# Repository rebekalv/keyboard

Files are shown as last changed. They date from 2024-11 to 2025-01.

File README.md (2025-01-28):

# 🚀 Build Your Dream Mechanical LED Keyboard with AVR DU! 🌟

Ever wanted to craft your own custom mechanical keyboard? Here's how I brought mine to life, step-by-step! 🛠️✨

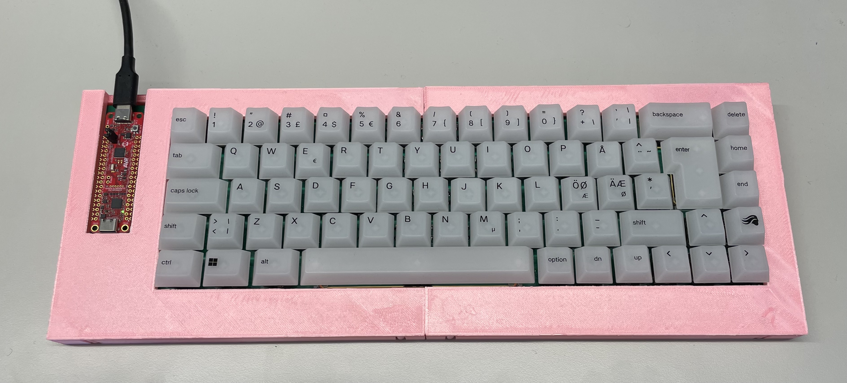
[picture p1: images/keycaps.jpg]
Mechanical Keyboard


---

### 🔧 **Project Highlights:**

- **Microcontroller Magic 🧠:**  
  Powered by the AVR64DU32 on a Curiosity Nano (cnano), this keyboard communicates seamlessly via USB-C using the Human Interface Device (HID) class. No soldering, no hassle—just plug and play!

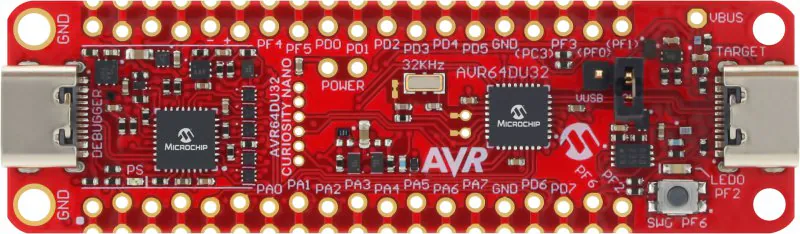
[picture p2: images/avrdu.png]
Microcontroller AVRDU
  

- **Custom PCB in KiCad 💻:**  
  I designed a PCB to eliminate complex wiring, ensuring a sleek, professional layout. KiCad made it easy to customize my PCB, but managing library includes can be somewhat cumbersome.

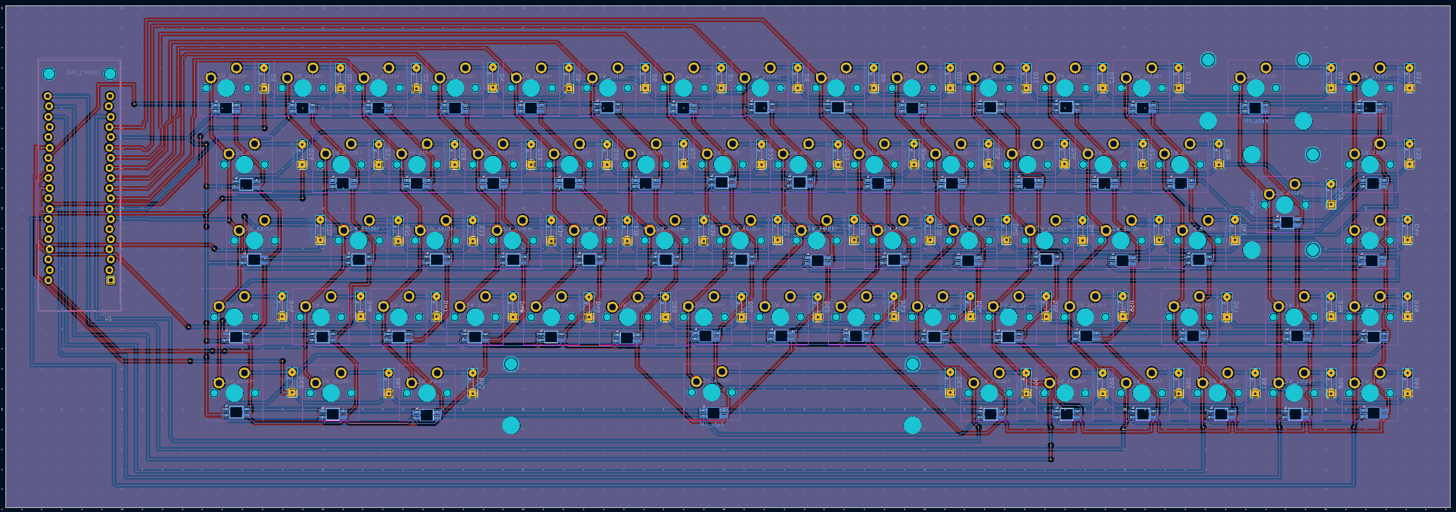
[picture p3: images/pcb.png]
pcb kicad
    

- **Light Up the Keys! 🌈:**  
  Each key features a NeoPixel-compatible LED beneath, adding customizable lighting effects. LEDs are programmed directly alongside the keyboard firmware using MPLAB X IDE. Imagine the rainbow possibilities! 🌟 Due to a pcb schematic error (red circles), the ground and led data pin were swapped. Which is why lighting the leds will have to wait untill the arrival of a new pcb.

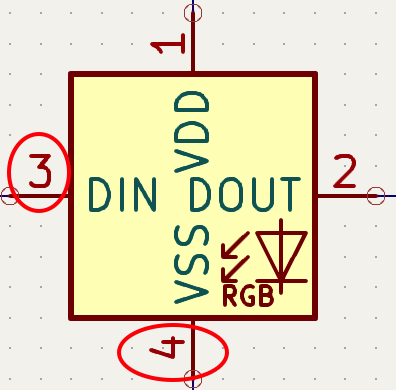
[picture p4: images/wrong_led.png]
wrong leds
     
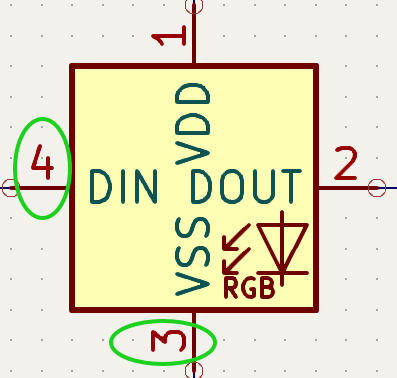
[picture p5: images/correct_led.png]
correct leds
     

- **Custom 3D-Printed Case 🎨:**  
  The case is here! Designed with simplicity and style, it’s split into five parts for easy 3D printing 🖨️. All .stl files are in the 3D_keyboard_case folder, ready to print and assemble.
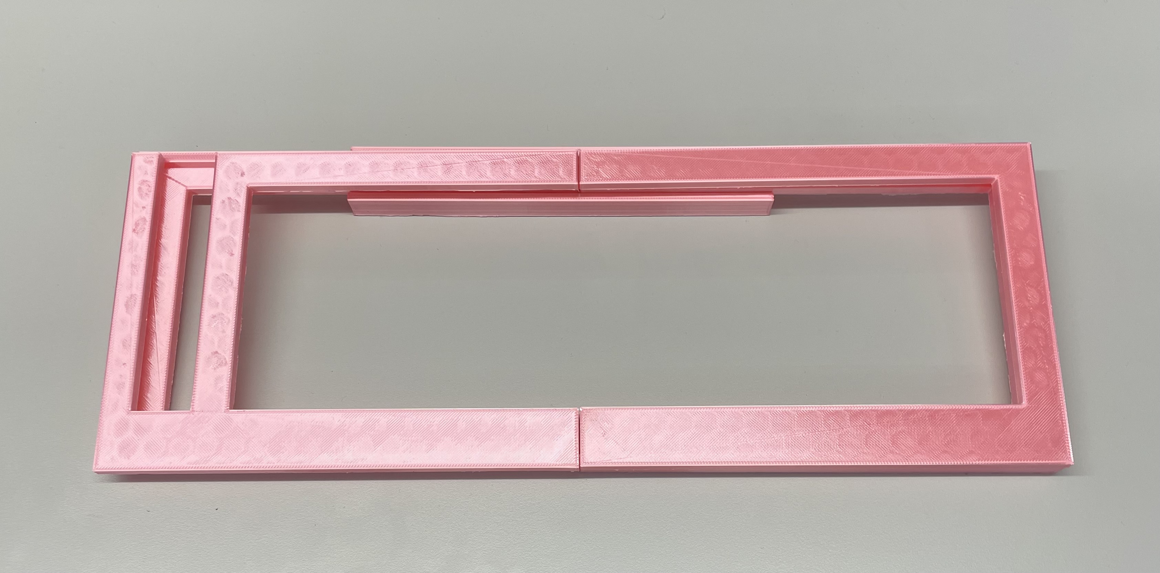
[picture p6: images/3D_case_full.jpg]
3D case
    

---

🎹 **DIY Tip:** If you're diving into mechanical keyboard projects, understanding matrix scanning and pcb tools like KiCad will open up endless customization!

Ready to create your own masterpiece? Let's type into the future! 🚀

## Component List
- Microcontroller: [AVR64DU32 curiosity nano](https://www.microchip.com/en-us/development-tool/ev59f82a)
- LEDs: [3.2x2.8mm sk6812 mini-E, reverse mount neopixel LEDs](https://www.aliexpress.com/item/1005005193716172.html)
- Diodes: [1N4148 DO-35 through hole diodes](https://www.aliexpress.com/item/1005006127068810.html)
- Switches: [JWICK V2 T1 Black Blue Tactile Switch 5pin RGB, Cherry MX](https://www.aliexpress.com/item/1005004226805283.html)
- Stabilizers for big switches: [PCB mounted Cherry MX stabilizers](https://es.aliexpress.com/item/1005004229140548.html)
- See-through Keycaps: [Polychroma V2 RGB Keycaps, Nordic ISO](https://www.maxgaming.no/no/keycaps/polychroma-v2-rgb-keycaps-131-pbt-polykarbonat-caps-nordic-iso)

## Milestones
1. 🖥️ [**Layout Creation:**](#layout-creation) Sketch the perfect keyboard design.
2. 🛠️ [**AVR Pin Setup:**](#avr-pin-setup) Map out pin connections and wiring.
3. 🔌 [**Component Selection:**](#component-selection) Choose the ideal switches, diodes, and LEDs.
4. 📐 [**PCB Design:**](#pcb-design) Craft your circuit board in KiCad and send it for manufacturing.
5. 🔧 [**Assembly:**](#assembly) Solder components onto the PCB.
6. 💻 [**Firmware Development:**](#firmware-development) Program the AVR for matrix scanning.
7. 🌈 **LED Integration:** Synchronize lighting with the firmware. (Suspended untill new pcb)
8. 🏗️ [**Case Design:**](#case-design) Plan and 3D print your custom keyboard case
9. 📚 **Document Everything:** Share your journey and insights.

### Layout Creation
I used https://www.keyboard-layout-editor.com/ to create an initial layout for my keyboard. If you want to regenerate this design, go to the website and insert the raw json data from `keyboard_layout/raw_data.json`. 

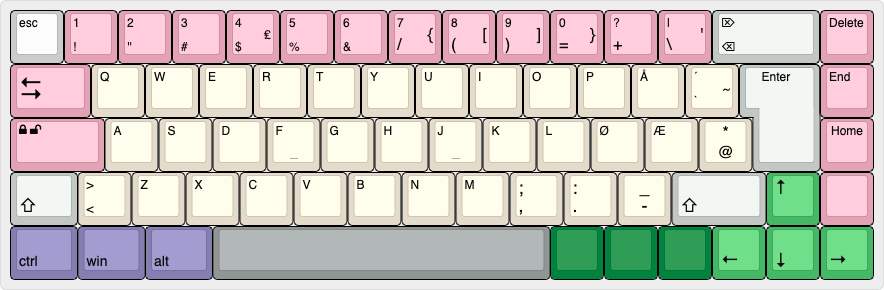
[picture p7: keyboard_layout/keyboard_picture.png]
keyboard layout
 

When your design is ready, you will need the outline of the keyboard for the pcb design. Go to https://plate.keeb.io/ and paste the raw json data. Then you can then download the outline as an svg file.

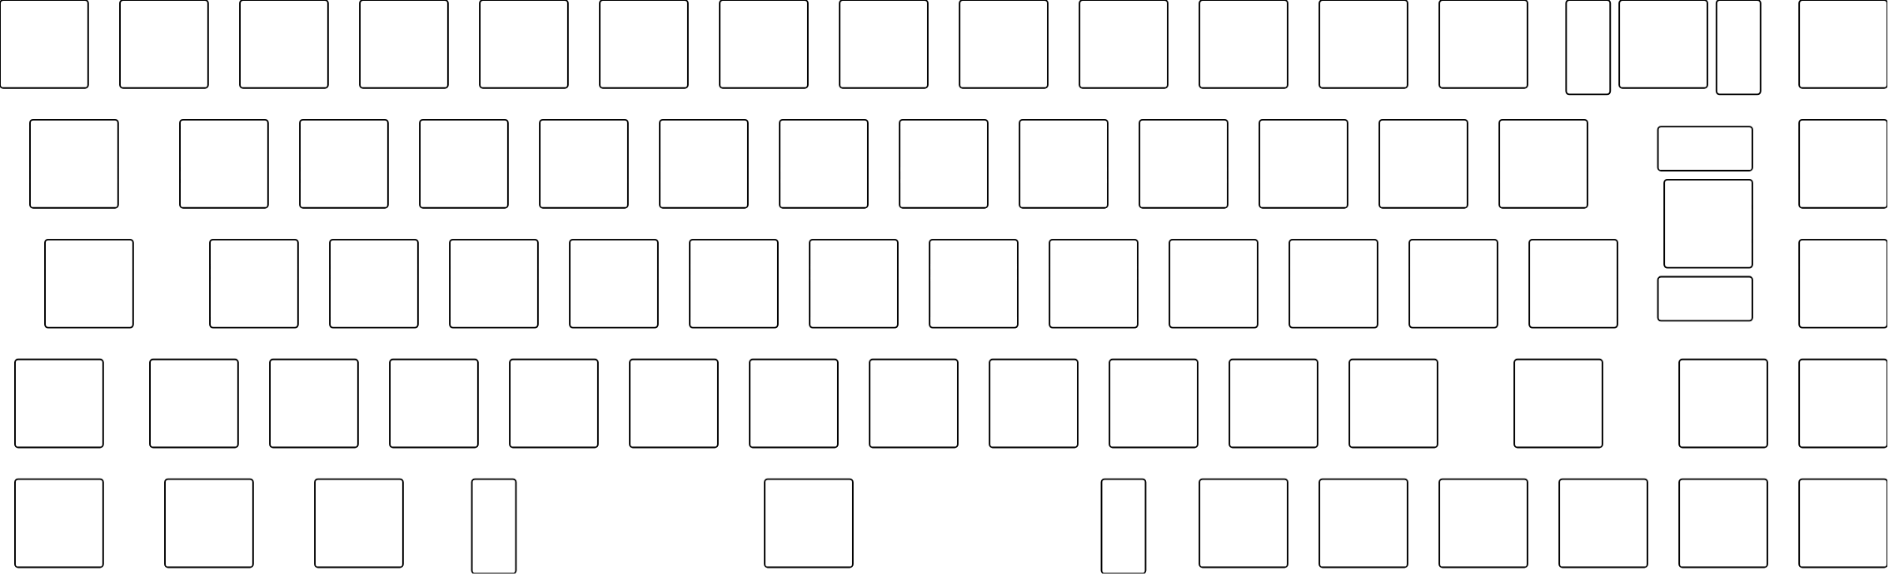
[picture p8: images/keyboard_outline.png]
keyboard outline


### AVR Pin Setup
The important thing in this step is to map out how many pins your keyboard needs, and if your microcontroller can provide that. My keyboard needs 5 rows and 15 columns, hence 20 pins. Looking at pinout on the [cnano website](https://www.microchip.com/en-us/development-tool/ev59f82a), it has 24 port pins. Excluding the usb detect, LED control and debugger LED pin, we are left with 21 available pins, which is enough for our keyboard.

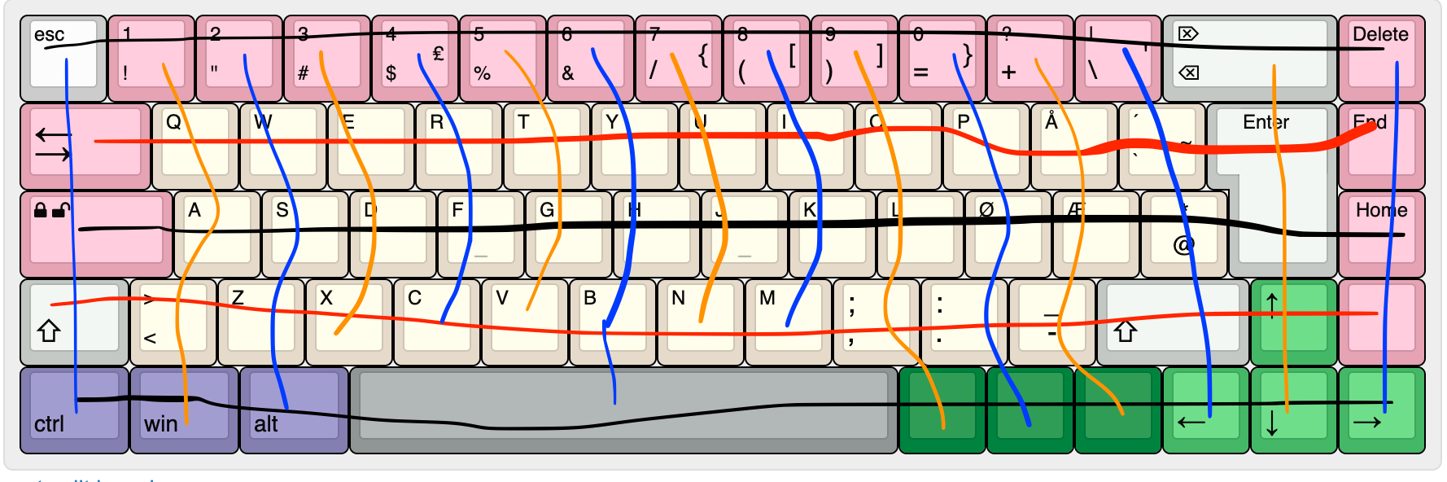
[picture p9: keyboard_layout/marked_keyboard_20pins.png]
keyboard columns and rows


Reading the datasheet for the avrdu, it reveals that the usart0 signal can be routed to 4 possible transmission pins. We will use this signal to control the leds, and I chose alternative 3, PD4, as the LED_DATA pin.

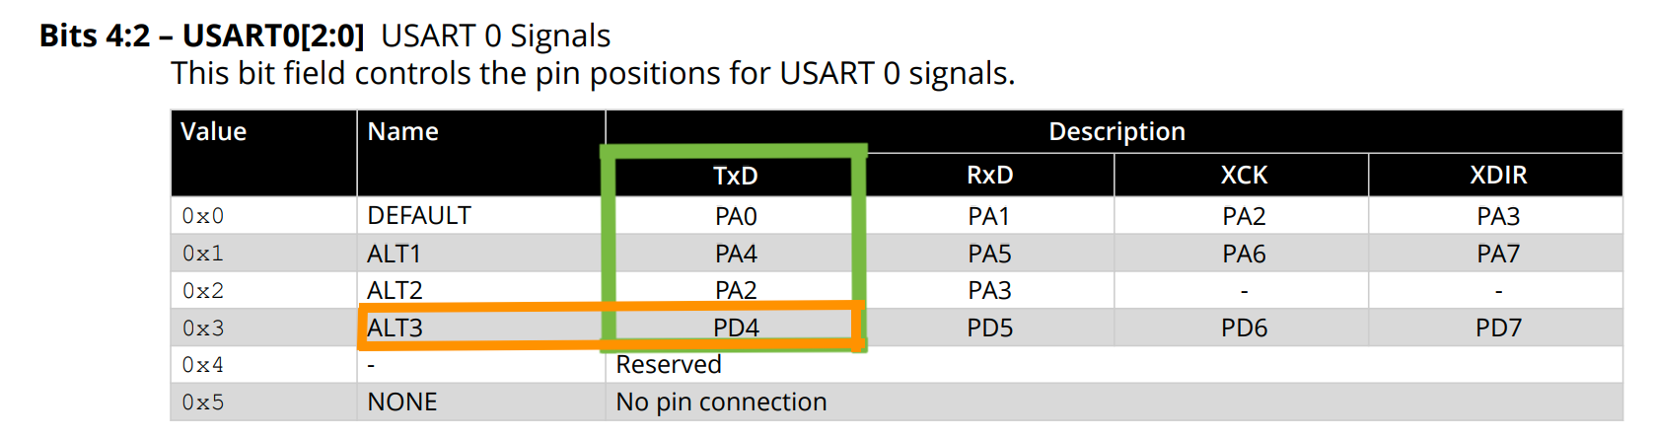
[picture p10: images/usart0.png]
usart0 transmission options


### Component Selection
Check the [component list](#component-list) for handy links! Going with popular, widely-used components simplifies the PCB design, because pre-existing footprints save time and effort. That's why I selected the reliable Cherry MX switches alongside the 1N4148 DO-35 diodes. Some Cherry MX switches feature an opening for LEDs to shine through, perfect for illuminating your keyboard (see the marking on the picture below). I opted to solder everything manually, so I chose through-hole diodes and ensured the LEDs were hand-solderable.

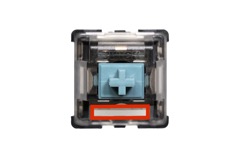
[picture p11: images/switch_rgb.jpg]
switch

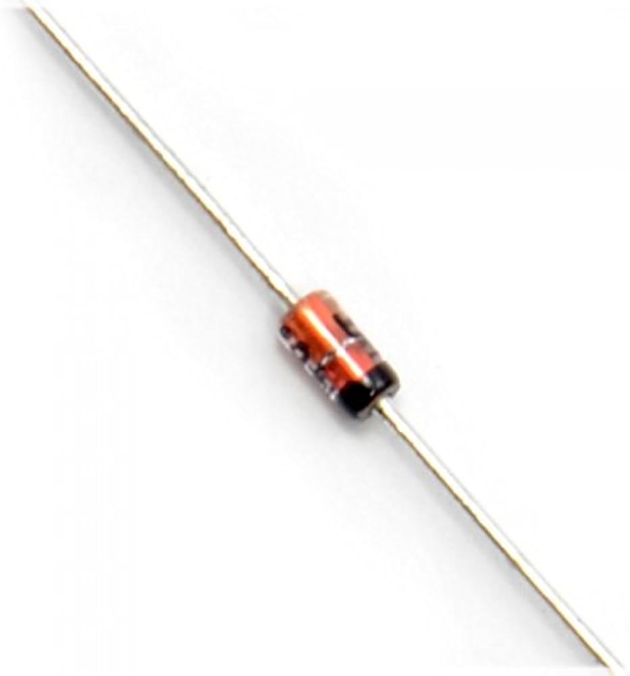
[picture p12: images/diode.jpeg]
diode

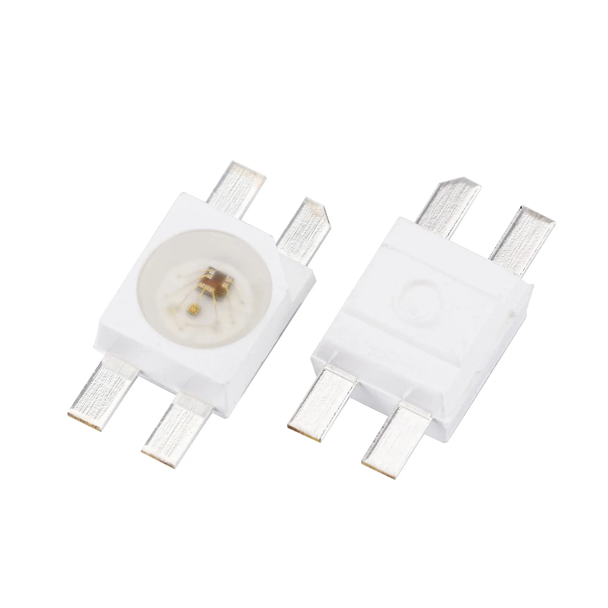
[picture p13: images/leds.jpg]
led


Pro tip: Also, go for PCB-mounted stabilizers—they're far easier to install than plate mounted, and the PCB outline already accommodates them.

stabilizer

### PCB Design
Now the real fun begins! 🚀 Or maybe the challenge? 🛠️

#### Schematic
In KiCad, you’ll start by creating a clear and accurate schematic. This is the blueprint for your circuit, mapping out connections between components and ensuring everything fits together logically. Double-check those connections and that the schema matches the data sheets—it’s much easier to catch errors here than on a finished PCB!

In my schematics, I connected all my switches and diodes and assigned them rows and columns as described in the keyboard outline. Further, I designed a symbol for the avrdu cnano, with the pinout corresponding to the datasheet. I connected the rows and columns to available port pins, and the grounds, voltages and led pin to their corresponding pins.

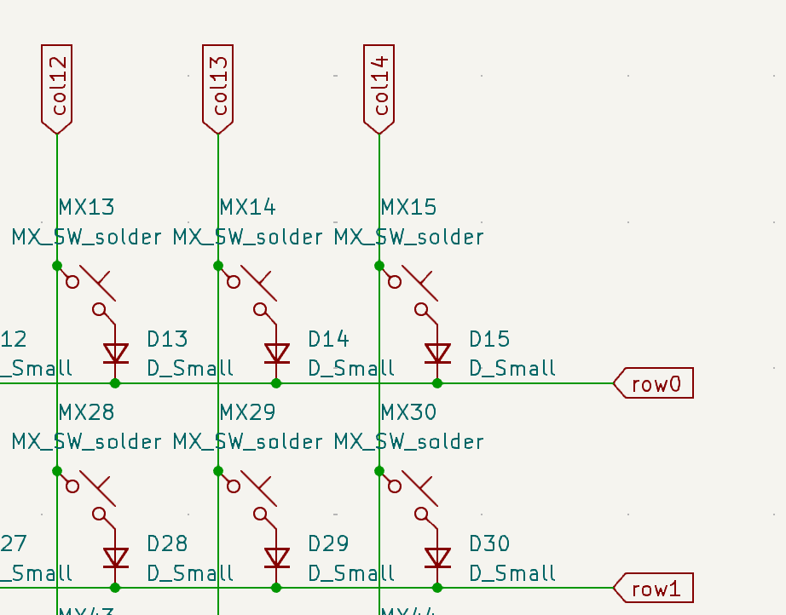
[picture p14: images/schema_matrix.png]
switch matrix

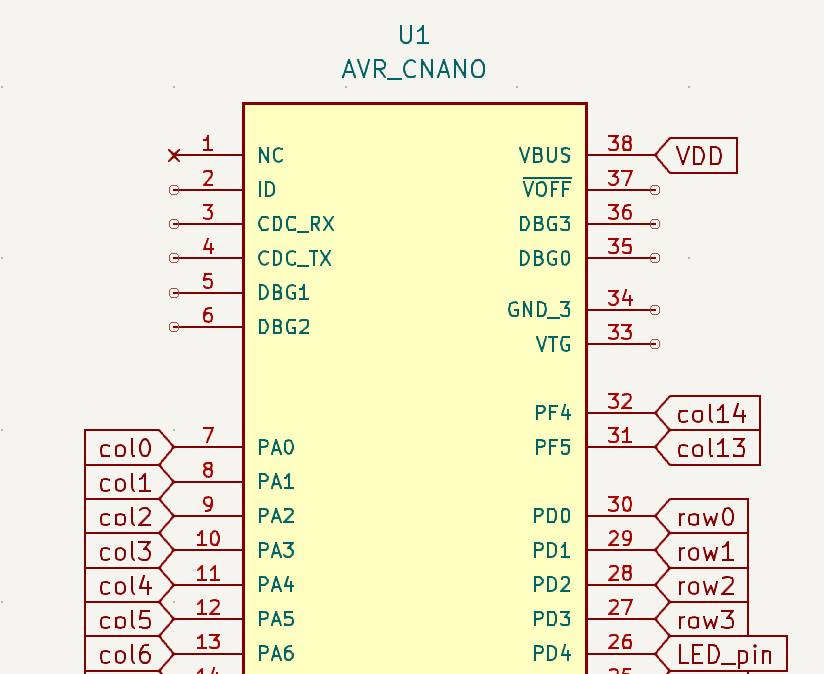
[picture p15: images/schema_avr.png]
avr schema

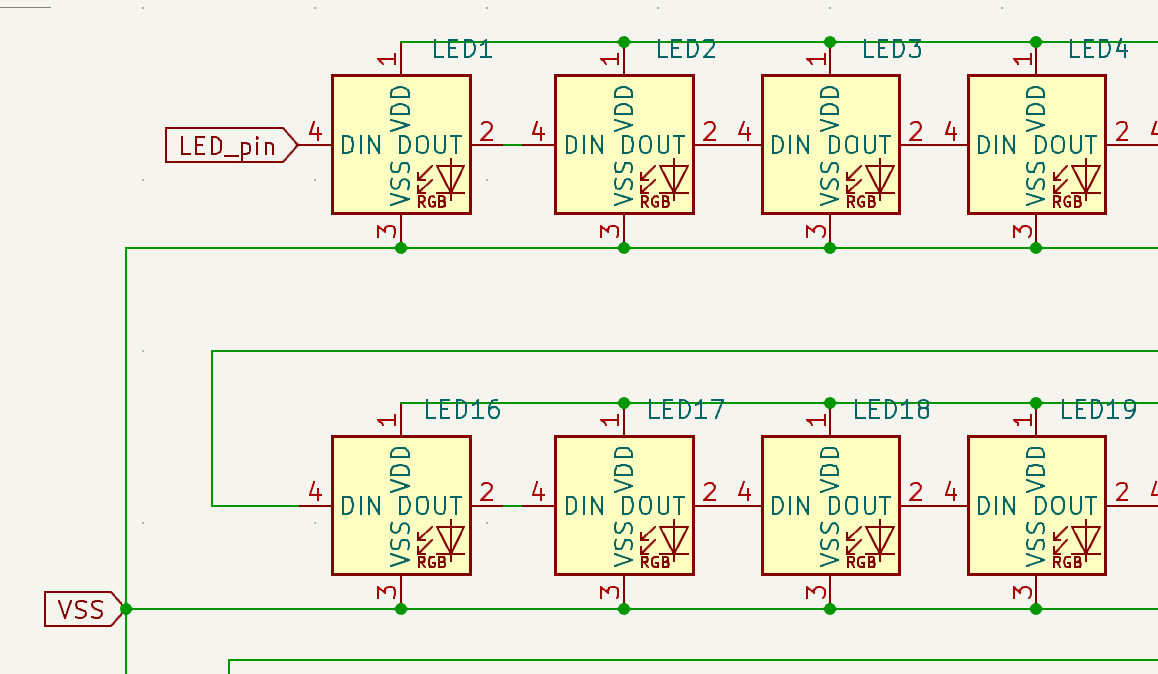
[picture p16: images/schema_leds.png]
led schema


#### PCB and 3D model
After completing the schematic, the next step is designing the PCB layout. In the pcb editor you can import the outline from `keyboard_layout/keyboard-outline.svg`, which lets you know where to place your components. 

Then you import all the components from the schematic and arrange the them according to your design outline. All the symbols from the schematics will be translated into their corresponding footprint, which can be a bit confunsing and I recommend watching a youtube video explaing in detail.

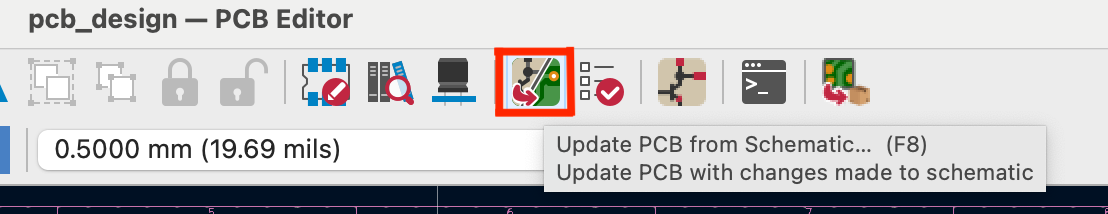
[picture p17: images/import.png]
import components


Now you need to route all the traces, which might be the most time consuming. The netlist, which is thin lines between your components, will show how everything should be connected.

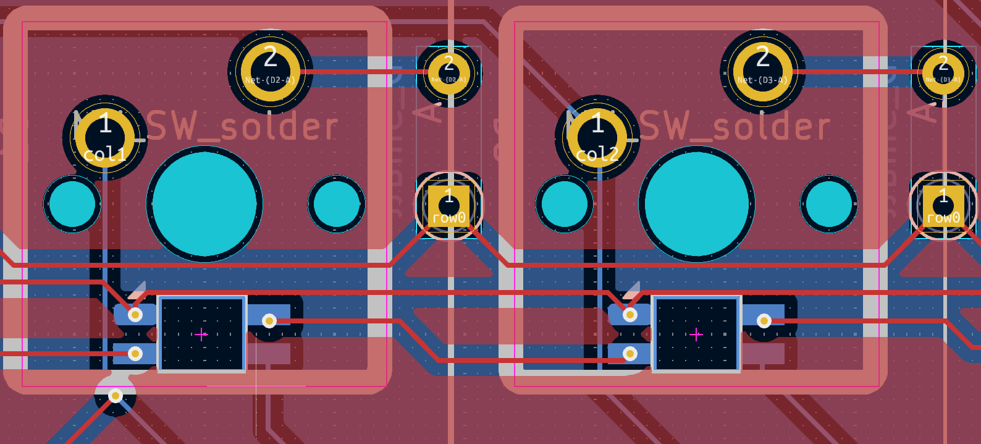
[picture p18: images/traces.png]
route traces


You can double check that your design matches your vision by using the 3D viewer in kicad and assigning .step files to all your footprints. Here is the 3d model of the front and the back of my pcb:

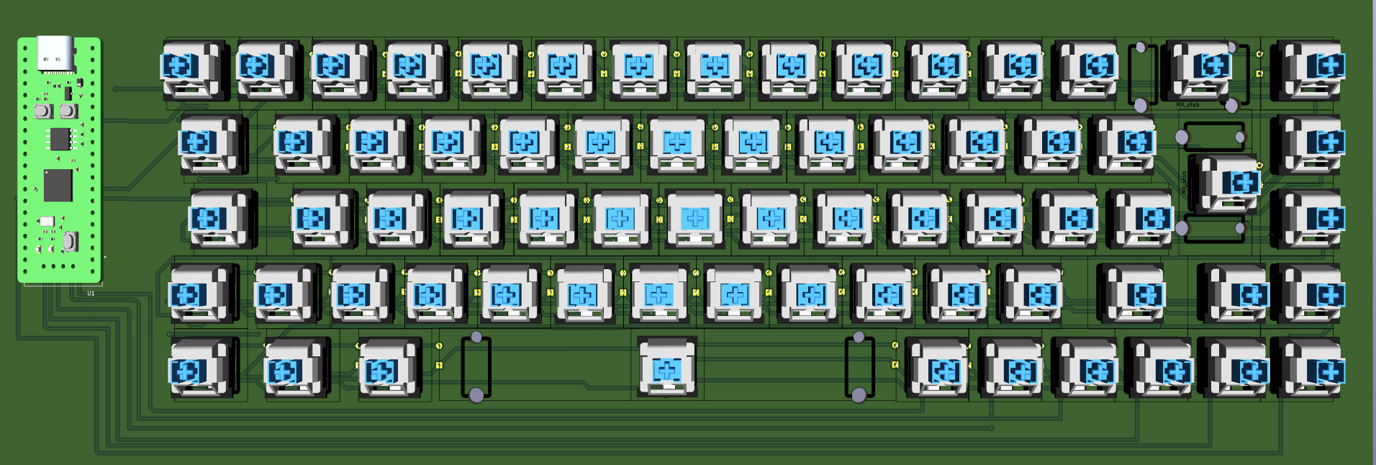
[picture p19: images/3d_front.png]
3d front

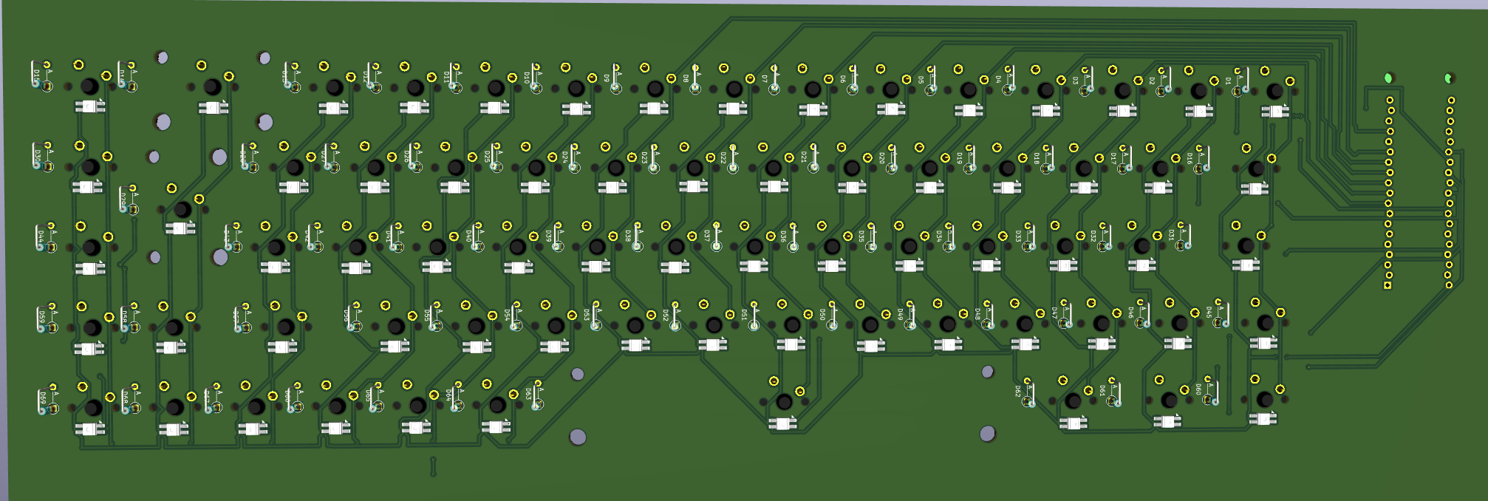
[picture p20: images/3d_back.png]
3d back


Now your design is ready for production! I used the fabrication tool kit in KiCad, to create a .zip file with gerber files. Then I went to https://jlcpcb.com/, uploaded the file and sent it to production. 

Pro tip: If there are no footprints available for your microcontroller, you can use footprints for similar microcontrollers and manually add or remove holes in the footprint editor to match you preffered controller.

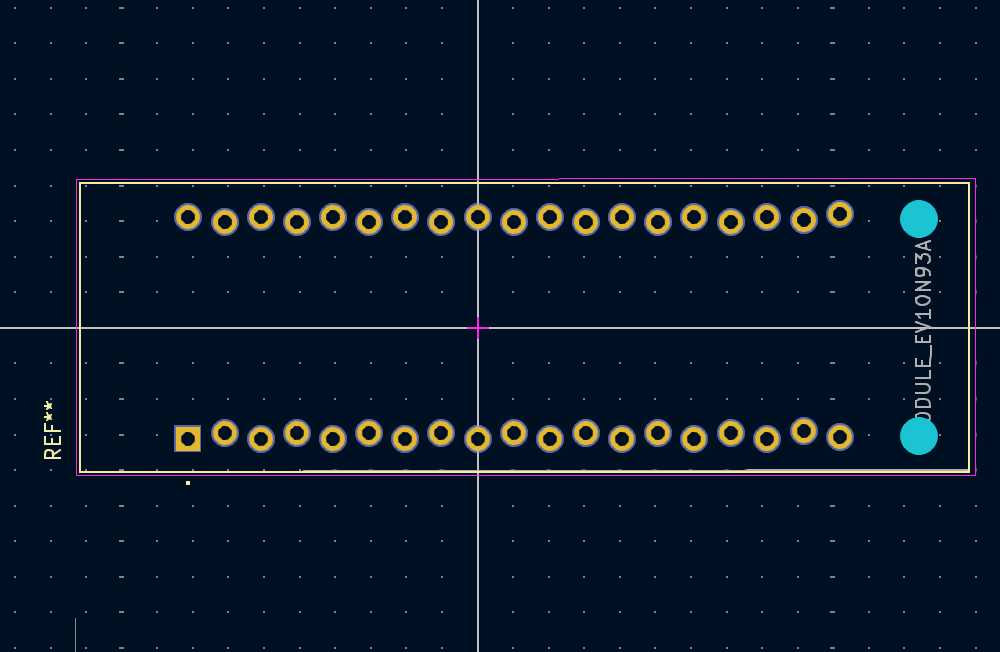
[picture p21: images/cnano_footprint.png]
cnano footprint editor


### Assembly
This is a very straight forward process where you solder your components on the pcb. Start with the diodes and leds and do the switches last. Here is the assembled keyboard with stabilizers:

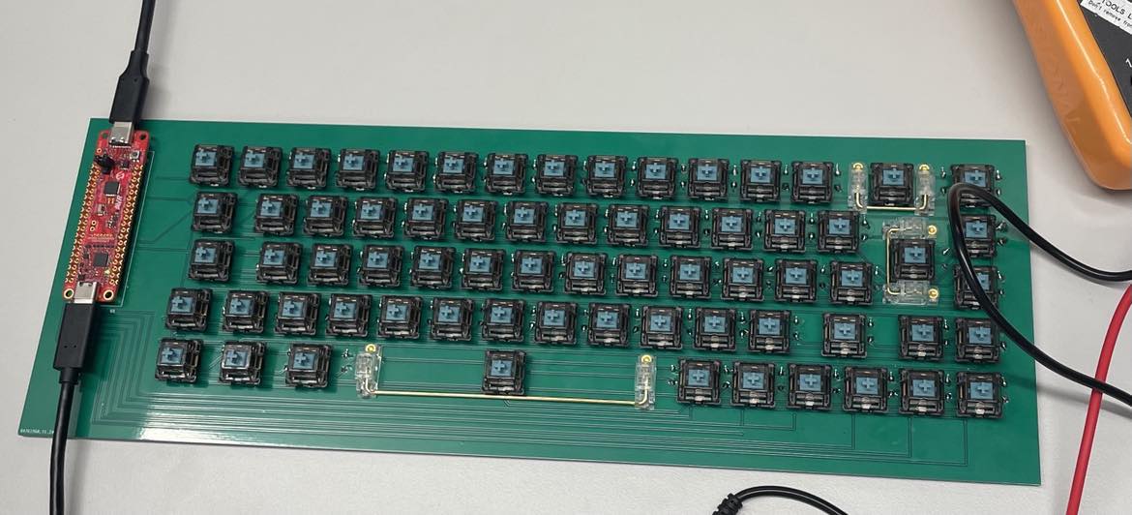
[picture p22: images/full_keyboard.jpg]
assembled pcb


### Firmware Development
The `full_keyboard_avrdu.X` project structure:
 - **usb**: For checking and maintaining the usb-c connection
 - **hardware**: Functions for scanning columns and activating rows
 - **main**: Handles keypresses and sends HID codes over usb
 - **keyboard**: Mapping of keypresses to HID codes
 - **led**: In progress, here you find general LED functions which I used in my summer project

#### Matrix Scanning
When a button is pressed, its column and its row are connected together. Since the active row is low, it will pull the column down, from high to low. The code sequentially activates each row and scans through all columns to detect keypresses. It detects both the change from high to low (key down) and from low to high (key up). This process is repeated continuously to monitor key presses.

```
void IterateColumns(void) // called every 1 ms
{  
    // Iterate columns
        // Check key down event
        // Check key up event
    }
    
    // Go to the next row
 
    return;
}
```

On each key change, press or release, a hid code is sent with either a press down or a press up event. 

```
void KeyPressHandler(uint8_t currentRow)
{
    DetectKeyChanges(currentRow);
    
    if (keyChanges)
    {
        if (keyDown)
        {
            KeyDownEvent();
        }
        else
        {
            KeyUpEvent();
        }
    }
}
```

For special characters, modifiers can be used (shift and ctrl). In my code I check if a keypress corresponds to a modifier and then send the modifier down or up event. 

### LED Integration
I used the usart0 in the AVR in spi mode, to create a pulse-width modulated signal for neopixel LEDs. This will be used later to control the color scheme of the LEDs, but is for now on hold.

### Case Design
The keyboard now has a home! I designed an awesome 3D keyboard case that’s both practical and fun 🎉. It’s split into five pieces to fit my 3D printer 🖨️ and is super easy to assemble. All the 3D modules are available in the 3D_keyboard_case folder as .stl files, ready to print in any color you want! 🛠️ For the creative minds, I’ve included the original DesignSpark Mechanical file 🖌️, so you can tweak, customize, or modify it using their 3D modeling software. Whether you glue it together, enhance it further, or leave it as is, this case is ready to elevate your keyboard project! 🚀🌈

  - Keyboard case top
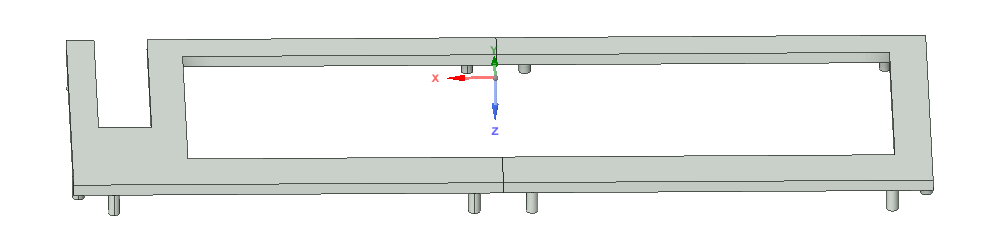
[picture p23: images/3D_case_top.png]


- Keyboard case bottom
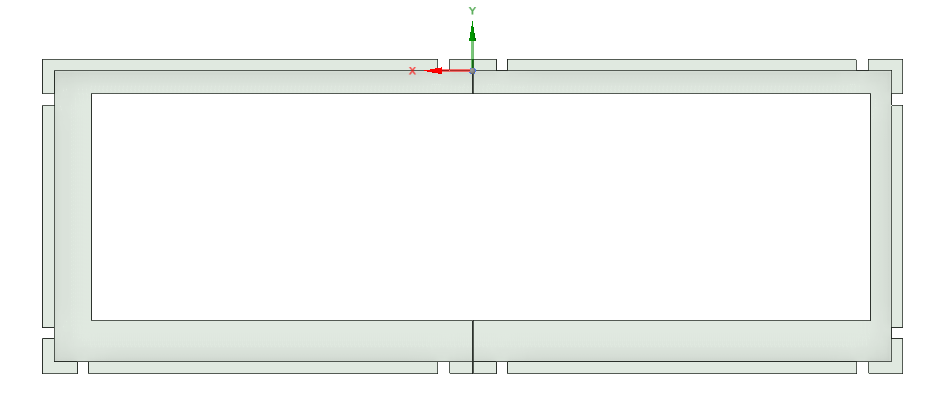
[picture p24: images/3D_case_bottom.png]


- Keyboard case tilted support
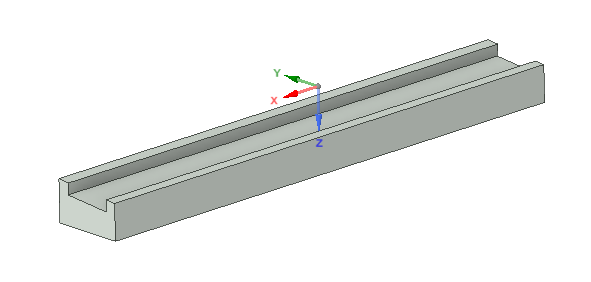
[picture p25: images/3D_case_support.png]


### Conclusion
Now you know how to create a custom, matrix keyboard using an AVR64DU32 Curiosity Nano. By using the USB-C HID class, our keyboard communicates directly with the computer and wiring was simplified using a custom made PCB. LEDs were included under each key and what is missing is to create a fitting case for the keyboard.

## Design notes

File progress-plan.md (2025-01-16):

# Custom Keyboard TFE4205
The goal of this course is to create a custom, matrix keyboard using an AVR64DU32 Curiosity Nano. The keyboard should be able to communicate directly with the computer through the USB-C Human Interface Device (HID) class. The usage of a custom made PCB will simplify the wiring, creating a seamless design. In addition, I aim to include LEDs under each key and to create a fitting case for the keyboard, either through 3D printing or through laser cutting.

## Learning Goals
    PCB design
    Matrix Keyboard wiring
    USB-C HID communication
    Matrix Keyboard programming and timing requirements
    LED timing requirements, especially if using Neopixel
    3D print design
    Laser cutting

## Progress Plan
    1. Create button layout
    2. Plan AVR pins and connections
    3. Decide size of switches with led holes
    4. Design PCB with diodes and leds: white
    5. Solder the PCB, leds, diodes, and switches
    6. Find suitable keycaps
    7. Program the AVR with matrix keyboard
    8. Program the AVR with leds
    9. Design and laser cut a case
    10. Create documentation

## Research
### Layout keyboard
- [Easy Keyboard Layout](http://www.keyboard-layout-editor.com/#/) Decide layout here.
- [Keyboard Layout shematic](https://plate.keeb.io/) This can be imported to PCB design to know where to place your switches. Design it to match the easy layout.
### Pin configuration inspiration
- [Egil AVR64DU32](https://microchiptechnology.sharepoint.com/sites/-Social-MicrochipNWY/Shared%20Documents/Forms/AllItems.aspx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)
- Pins to connect usb: vusb, dm, dp, gnd (6, 7, 8, 19)
- Pins to program the avr: gnd, vdd, updi=PF7, reset=PF6 (29, 28, 27, 26)
- Pin to control LEDS: PA0 (30)
- Pin to check voltage/connection: AINP4 = PC3 (9)
- Extra non-programmable pins: vdd (18)
- Programmable pins: 32 - 4 - 4 - 1 - 1 - 1 = 21 (need 20 total for rows + columns)
### Switches tactile 
- [Hænrik switches aliexpress](https://www.aliexpress.com/item/1005004226805283.html)
- JWICK V2 T1 Black Blue Tactile Switch 5pin RGB
- Buy between 80 and 100 pieces.
- Hole for leds are 10mm x 3mm 
### Keycaps
- [Keycaps maxgaming](https://www.maxgaming.no/no/datatilbehor/tastatur/keycaps)
- Buy norwegian caps.
- Test out 3D printing keycaps
### LEDs and diodes
- 1N4148 Diodes [Aliexpress DO-35 through hole diodes](https://www.aliexpress.com/item/1005006127068810.html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)
- [2.0x1.8mm LEDS ws2812b 2020 neopixel](https://www.mouser.com/pdfDocs/WS2812B-2020_V10_EN_181106150240761.pdf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)
- [Leds soldered on the front](https://www.eevblog.com/forum/manufacture/advice-for-design-of-keyboard-pcb/)
- [3.2x2.8mm LEDS sk6803 mini-E. Soldered on the back, need hole](https://www.aliexpress.com/item/1005003636607308.html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,scm-url:1007.40050.354490.0,pvid:26edec55-466f-4dbb-9192-bd1cba5853b7,tpp_buckets:668%232846%238116%232002&pdp_npi=4%40dis%21EUR%2111.63%210.91%21%21%2112.64%210.98%21%40210384db17265815929271181e528b%2112000026925008542%21rec%21NO%21%21ABX&utparam-url=scene%3ApcDetailTopMoreOtherSeller%7Cquery_from%3A#nav-specification)
- JLC pcb? To produce my pcb.

### PCB 
- Circuit Maker. More userfriendly that Kicad, but it has limitations since it is the free version of Altium.
- Kicad, good I like it.
- [Youtube Kicad](https://www.youtube.com/watch?v=8WXpGTIbxlQ)
- Ensure that the side you will solder on is opposite of the way you plan to put the switch. Order test 10x10?
- MX 1 switch as footprint?
### Automatic key configuration (not relevant)
- QMK, future potential for AVR driver supporting this firmware configurator
- Another one exists too, but that is more expensive.

### Questions
- Which leds should i use? Placement?
- bluetooth?
- usb-c connector?

### AVR
- [Footprint for avr64du32](https://app.ultralibrarian.com/details/a1da6b9f-fbed-11ee-80cc-0210d3b76207/Microchip/AVR64DU32-I-PT)

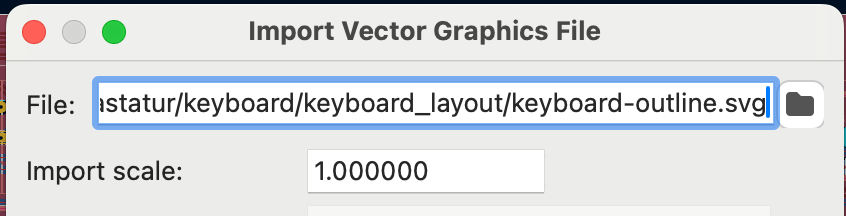
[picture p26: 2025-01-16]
images/outline.png

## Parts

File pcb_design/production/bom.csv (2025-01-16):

Designator | Footprint | Quantity | Value | LCSC Part #
D1, D10, D11, D12, D13, D14, D15, D16, D17, D18, D19, D2, D20, D21, D22, D23, D24, D25, D26, D27, D28, D29, D3, D30, D31, D32, D33, D34, D35, D36, D37, D38, D39, D4, D40, D41, D42, D43, D44, D45, D46, D47, D48, D49, D5, D50, D51, D52, D53, D54, D55, D56, D57, D58, D59, D6, D60, D61, D62, D63, D64, D65, D66, D67, D68, D69, D7, D8, D9 | D_DO-35_SOD27_P5.08mm_Vertical_AnodeUp | 69 | D_Small
LED1, LED10, LED11, LED12, LED13, LED14, LED15, LED16, LED17, LED18, LED19, LED2, LED20, LED21, LED22, LED23, LED24, LED25, LED26, LED27, LED28, LED29, LED3, LED30, LED31, LED32, LED33, LED34, LED35, LED36, LED37, LED38, LED39, LED4, LED40, LED41, LED42, LED43, LED44, LED45, LED46, LED47, LED48, LED49, LED5, LED50, LED51, LED52, LED53, LED54, LED55, LED56, LED57, LED58, LED59, LED6, LED60, LED61, LED62, LED63, LED64, LED65, LED66, LED67, LED68, LED69, LED7, LED8, LED9 | SK6812-MINI-E | 69 | SK6812MINI-E
MX1, MX10, MX11, MX12, MX13, MX14, MX15, MX16, MX17, MX18, MX19, MX2, MX20, MX21, MX22, MX23, MX24, MX25, MX26, MX27, MX28, MX29, MX3, MX30, MX31, MX32, MX33, MX34, MX35, MX36, MX37, MX38, MX39, MX4, MX40, MX41, MX42, MX43, MX44, MX45, MX46, MX47, MX48, MX49, MX5, MX50, MX51, MX52, MX53, MX54, MX55, MX56, MX57, MX58, MX59, MX6, MX60, MX61, MX62, MX63, MX64, MX65, MX66, MX67, MX68, MX69, MX7, MX8, MX9 | SW_MX_1u | 69 | MX_SW_solder
S1 | STAB_MX_6.25u | 1 | MX_stab
S2, S3 | STAB_MX_2u | 2 | MX_stab
U1 | cnano | 1 | AVR_CNANO

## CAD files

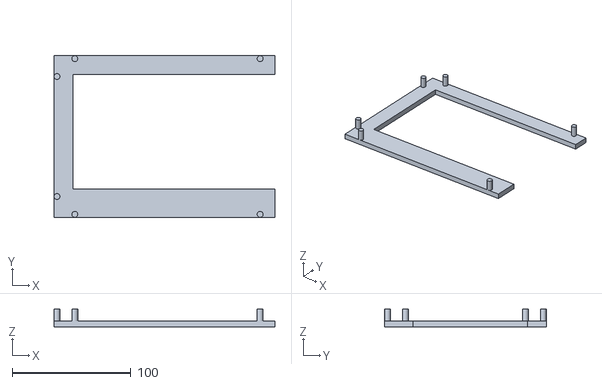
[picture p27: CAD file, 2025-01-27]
3D_keyboard_case/keyboard_top_right.stl
186.0 x 136.0 x 15.0

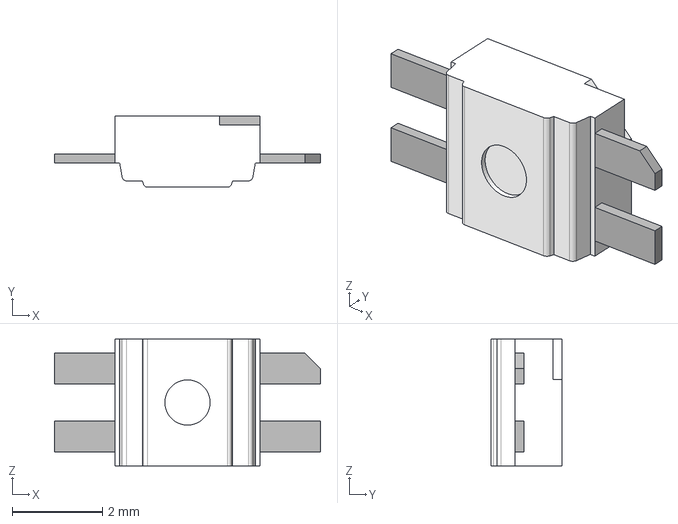
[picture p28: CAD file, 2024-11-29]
kicad_extra/3d_models_extra/SK6812MINI-E v1.step
5.88 x 1.58 x 2.80 mm

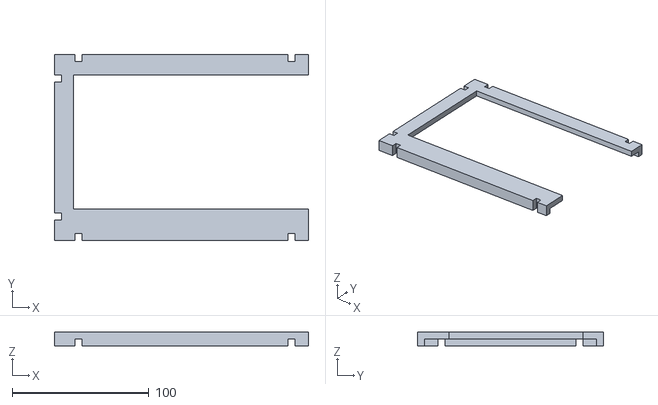
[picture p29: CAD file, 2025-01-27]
3D_keyboard_case/keyboard_bottom_right.stl
186.0 x 136.0 x 10.0

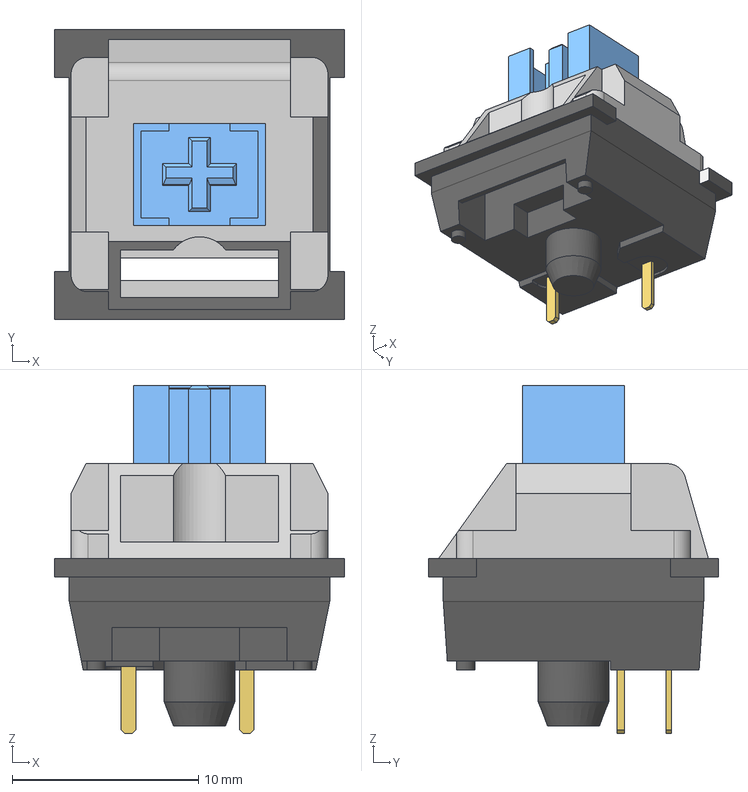
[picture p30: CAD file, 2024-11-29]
kicad_extra/3d_models_extra/MX_SW_RGB.stp
15.6 x 15.6 x 18.7 mm
Button
Pins

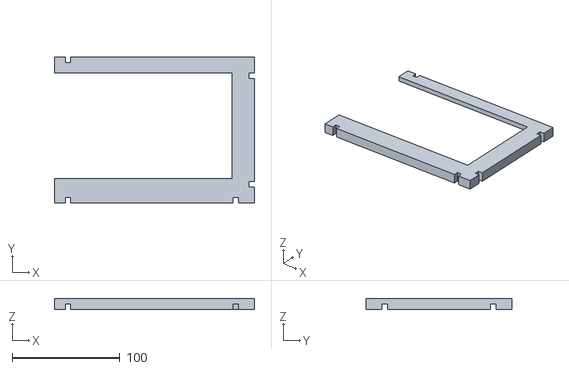
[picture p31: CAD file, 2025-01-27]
3D_keyboard_case/keyboard_bottom_left.stl
186.0 x 136.0 x 10.0

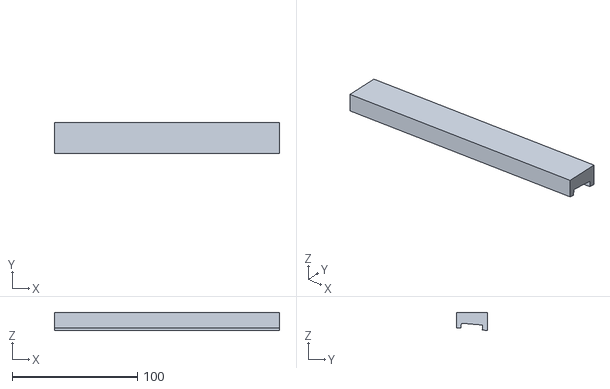
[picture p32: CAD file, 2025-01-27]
3D_keyboard_case/keyboard_support.stl
180.0 x 25.0 x 14.5

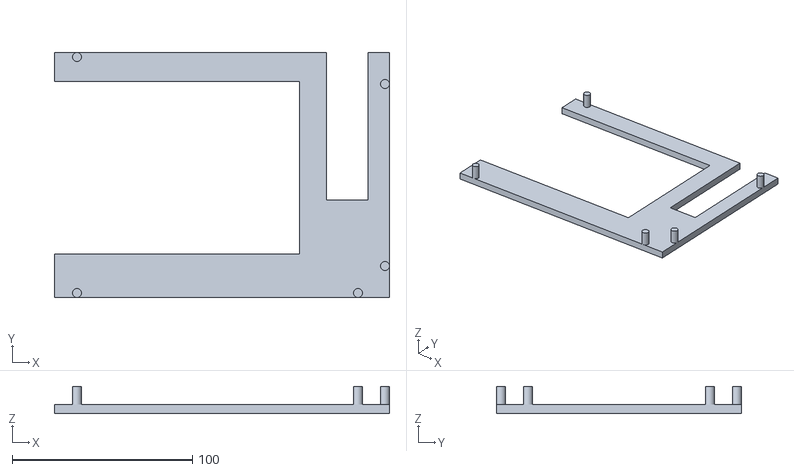
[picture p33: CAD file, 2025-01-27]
3D_keyboard_case/keyboard_top_left.stl
186.0 x 136.0 x 15.0

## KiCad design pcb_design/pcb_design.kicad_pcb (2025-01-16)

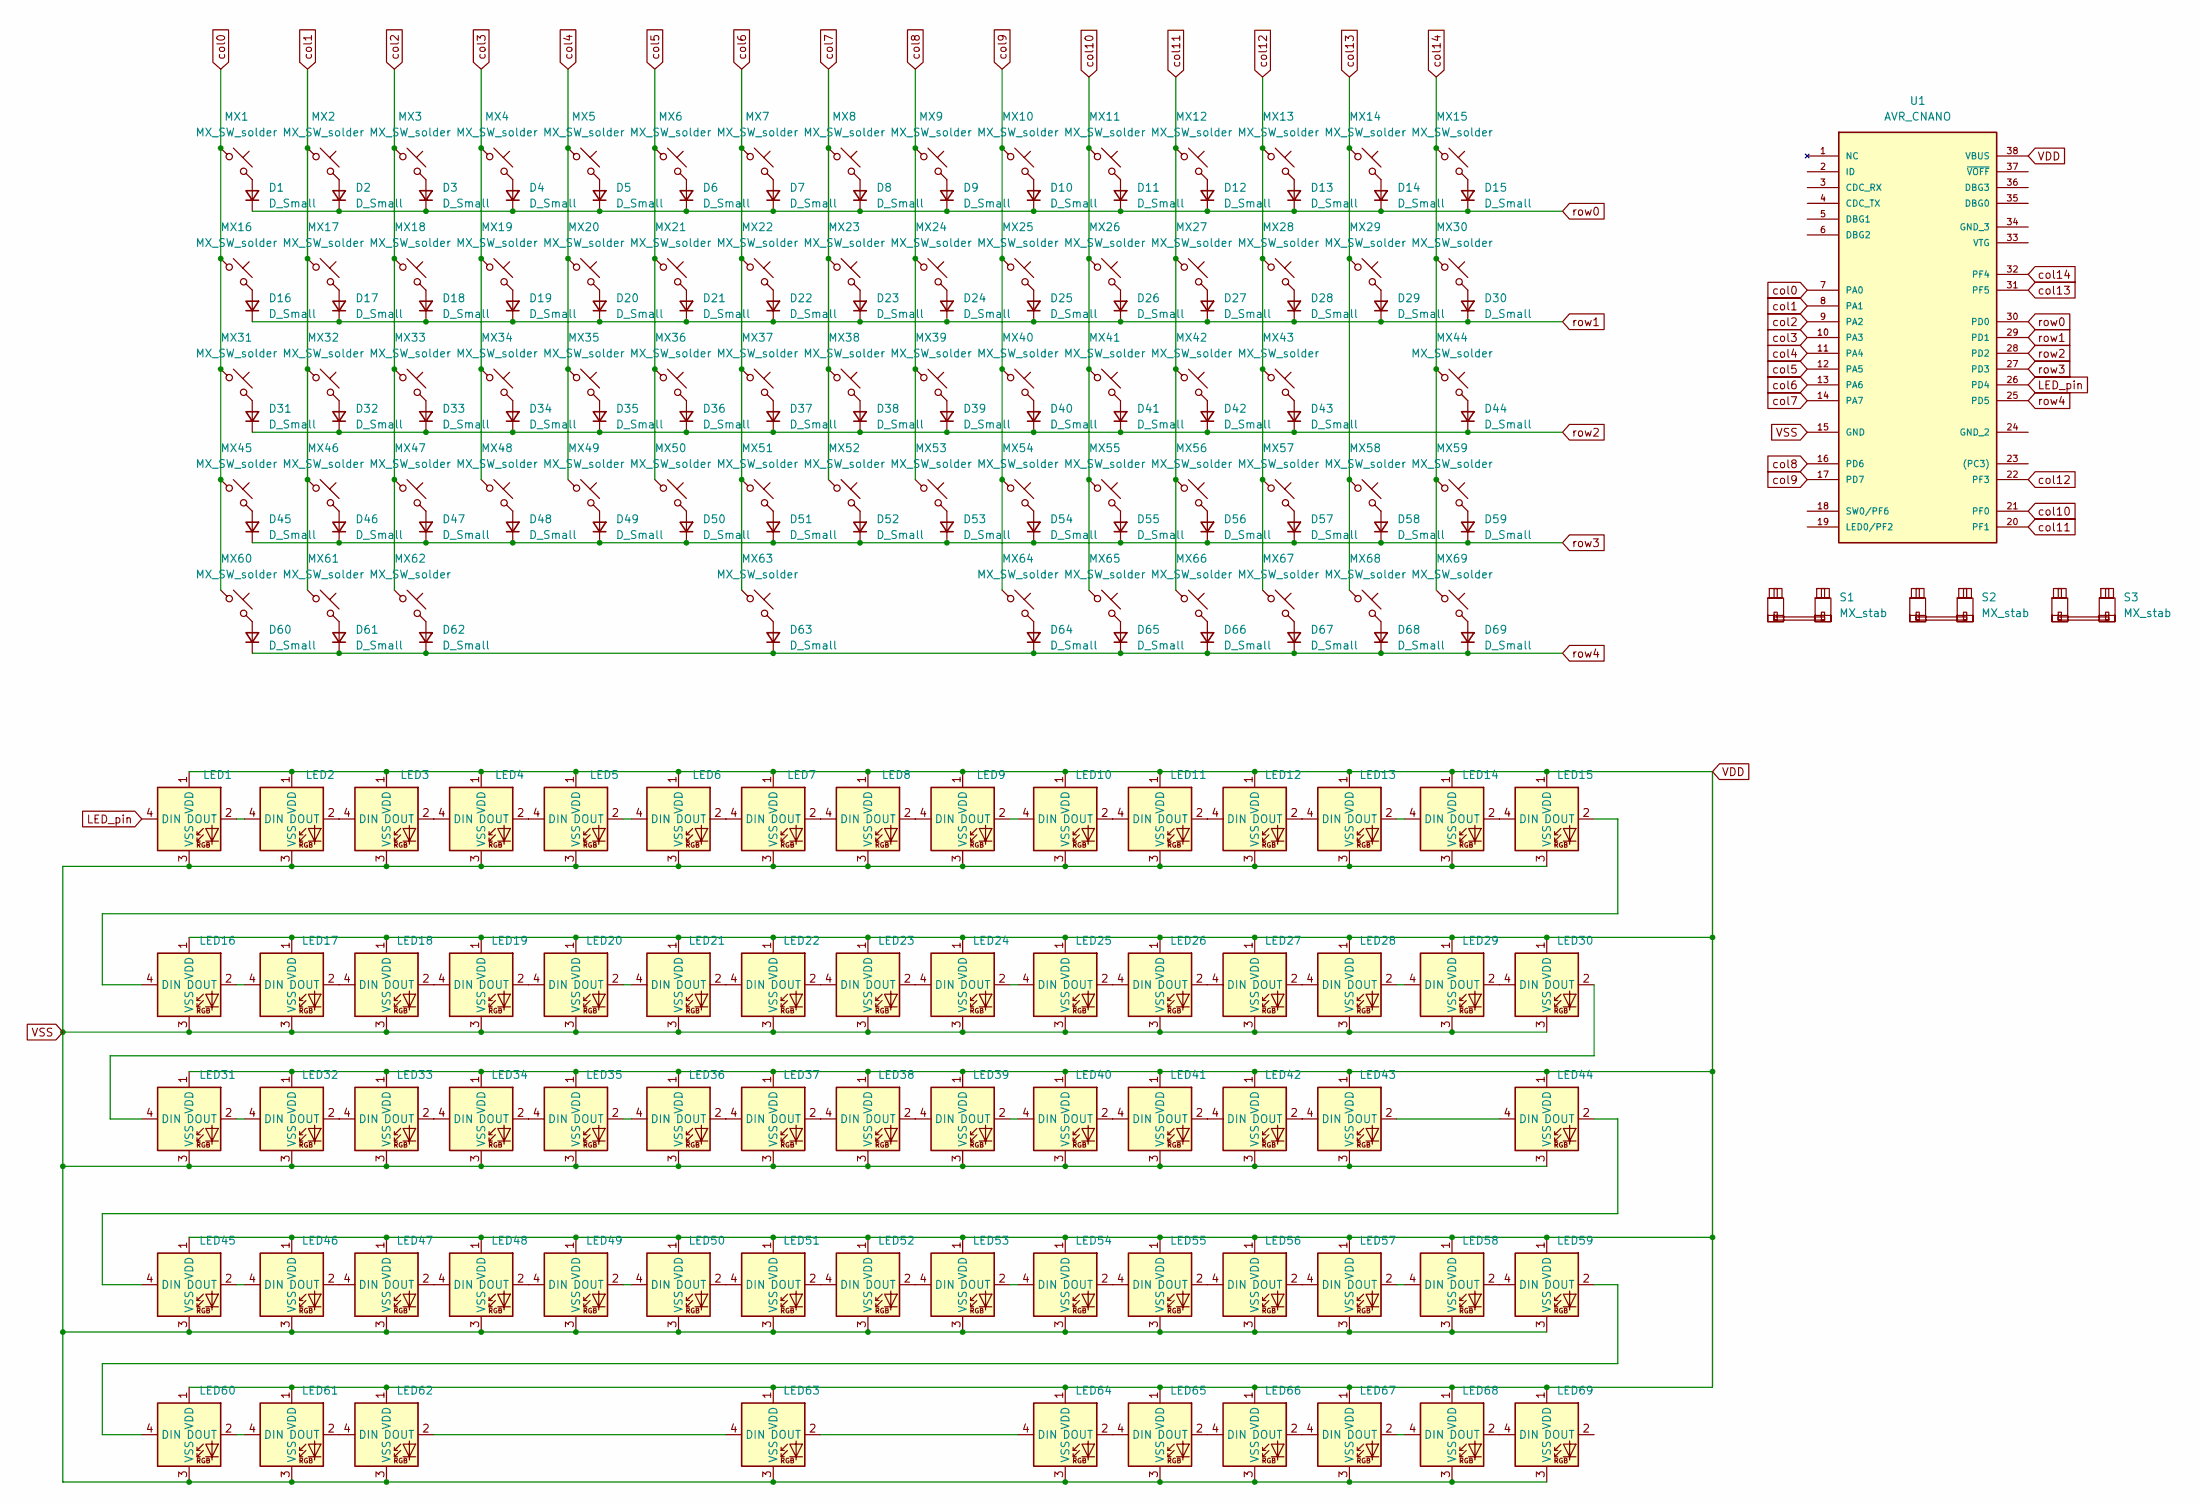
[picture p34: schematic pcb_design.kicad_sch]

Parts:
D1, D2, D3, D4, D5, D6, D7, D8, D9, D10, D11, D12, D13, D14, D15, D16, D17, D18, D19, D20, D21, D22, D23, D24, D25, D26, D27, D28, D29, D30, D31, D32, D33, D34, D35, D36, D37, D38, D39, D40, D41, D42, D43, D44, D45, D46, D47, D48, D49, D50, D51, D52, D53, D54, D55, D56, D57, D58, D59, D60, D61, D62, D63, D64, D65, D66, D67, D68, D69: D_Small; D_DO-35_SOD27_P5.08mm_Vertical_AnodeUp
LED1, LED2, LED3, LED4, LED5, LED6, LED7, LED8, LED9, LED10, LED11, LED12, LED13, LED14, LED15, LED16, LED17, LED18, LED19, LED20, LED21, LED22, LED23, LED24, LED25, LED26, LED27, LED28, LED29, LED30, LED31, LED32, LED33, LED34, LED35, LED36, LED37, LED38, LED39, LED40, LED41, LED42, LED43, LED44, LED45, LED46, LED47, LED48, LED49, LED50, LED51, LED52, LED53, LED54, LED55, LED56, LED57, LED58, LED59, LED60, LED61, LED62, LED63, LED64, LED65, LED66, LED67, LED68, LED69: SK6812MINI-E; SK6812-MINI-E
MX1, MX2, MX3, MX4, MX5, MX6, MX7, MX8, MX9, MX10, MX11, MX12, MX13, MX14, MX15, MX16, MX17, MX18, MX19, MX20, MX21, MX22, MX23, MX24, MX25, MX26, MX27, MX28, MX29, MX30, MX31, MX32, MX33, MX34, MX35, MX36, MX37, MX38, MX39, MX40, MX41, MX42, MX43, MX44, MX45, MX46, MX47, MX48, MX49, MX50, MX51, MX52, MX53, MX54, MX55, MX56, MX57, MX58, MX59, MX60, MX61, MX62, MX63, MX64, MX65, MX66, MX67, MX68, MX69: MX_SW_solder; SW_MX_1u
S1: MX_stab; STAB_MX_6.25u
S2, S3: MX_stab; STAB_MX_2u
U1: AVR_CNANO; cnano; PARTREV A

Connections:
LED_pin: LED1.4 (DIN), U1.26 (PD4)
unnamed: D1.2 (A), MX1.2
unnamed: D2.2 (A), MX2.2
unnamed: D3.2 (A), MX3.2
unnamed: D4.2 (A), MX4.2
unnamed: D5.2 (A), MX5.2
unnamed: D6.2 (A), MX6.2
unnamed: D7.2 (A), MX7.2
unnamed: D8.2 (A), MX8.2
unnamed: D9.2 (A), MX9.2
unnamed: D10.2 (A), MX10.2
unnamed: D11.2 (A), MX11.2
unnamed: D12.2 (A), MX12.2
unnamed: D13.2 (A), MX13.2
unnamed: D14.2 (A), MX14.2
unnamed: D15.2 (A), MX15.2
unnamed: D16.2 (A), MX16.2
unnamed: D17.2 (A), MX17.2
unnamed: D18.2 (A), MX18.2
unnamed: D19.2 (A), MX19.2
unnamed: D20.2 (A), MX20.2
unnamed: D21.2 (A), MX21.2
unnamed: D22.2 (A), MX22.2
unnamed: D23.2 (A), MX23.2
unnamed: D24.2 (A), MX24.2
unnamed: D25.2 (A), MX25.2
unnamed: D26.2 (A), MX26.2
unnamed: D27.2 (A), MX27.2
unnamed: D28.2 (A), MX28.2
unnamed: D29.2 (A), MX29.2
unnamed: D30.2 (A), MX30.2
unnamed: D31.2 (A), MX31.2
unnamed: D32.2 (A), MX32.2
unnamed: D33.2 (A), MX33.2
unnamed: D34.2 (A), MX34.2
unnamed: D35.2 (A), MX35.2
unnamed: D36.2 (A), MX36.2
unnamed: D37.2 (A), MX37.2
unnamed: D38.2 (A), MX38.2
unnamed: D39.2 (A), MX39.2
unnamed: D40.2 (A), MX40.2
unnamed: D41.2 (A), MX41.2
unnamed: D42.2 (A), MX42.2
unnamed: D43.2 (A), MX43.2
unnamed: D44.2 (A), MX44.2
unnamed: D45.2 (A), MX45.2
unnamed: D46.2 (A), MX46.2
unnamed: D47.2 (A), MX47.2
unnamed: D48.2 (A), MX48.2
unnamed: D49.2 (A), MX49.2
unnamed: D50.2 (A), MX50.2
unnamed: D51.2 (A), MX51.2
unnamed: D52.2 (A), MX52.2
unnamed: D53.2 (A), MX53.2
unnamed: D54.2 (A), MX54.2
unnamed: D55.2 (A), MX55.2
unnamed: D56.2 (A), MX56.2
unnamed: D57.2 (A), MX57.2
unnamed: D58.2 (A), MX58.2
unnamed: D59.2 (A), MX59.2
unnamed: D60.2 (A), MX60.2
unnamed: D61.2 (A), MX61.2
unnamed: D62.2 (A), MX62.2
unnamed: D63.2 (A), MX63.2
unnamed: D64.2 (A), MX64.2
unnamed: D65.2 (A), MX65.2
unnamed: D66.2 (A), MX66.2
unnamed: D67.2 (A), MX67.2
unnamed: D68.2 (A), MX68.2
unnamed: D69.2 (A), MX69.2
unnamed: LED1.2 (DOUT), LED2.4 (DIN)
unnamed: LED2.2 (DOUT), LED3.4 (DIN)
unnamed: LED3.2 (DOUT), LED4.4 (DIN)
unnamed: LED4.2 (DOUT), LED5.4 (DIN)
unnamed: LED5.2 (DOUT), LED6.4 (DIN)
unnamed: LED6.2 (DOUT), LED7.4 (DIN)
unnamed: LED7.2 (DOUT), LED8.4 (DIN)
unnamed: LED8.2 (DOUT), LED9.4 (DIN)
unnamed: LED10.2 (DOUT), LED11.4 (DIN)
unnamed: LED9.2 (DOUT), LED10.4 (DIN)
unnamed: LED11.2 (DOUT), LED12.4 (DIN)
unnamed: LED12.2 (DOUT), LED13.4 (DIN)
unnamed: LED13.2 (DOUT), LED14.4 (DIN)
unnamed: LED14.2 (DOUT), LED15.4 (DIN)
unnamed: LED15.2 (DOUT), LED16.4 (DIN)
unnamed: LED16.2 (DOUT), LED17.4 (DIN)
unnamed: LED17.2 (DOUT), LED18.4 (DIN)
unnamed: LED18.2 (DOUT), LED19.4 (DIN)
unnamed: LED19.2 (DOUT), LED20.4 (DIN)
unnamed: LED20.2 (DOUT), LED21.4 (DIN)
unnamed: LED21.2 (DOUT), LED22.4 (DIN)
unnamed: LED22.2 (DOUT), LED23.4 (DIN)
unnamed: LED23.2 (DOUT), LED24.4 (DIN)
unnamed: LED24.2 (DOUT), LED25.4 (DIN)
unnamed: LED25.2 (DOUT), LED26.4 (DIN)
unnamed: LED26.2 (DOUT), LED27.4 (DIN)
unnamed: LED27.2 (DOUT), LED28.4 (DIN)
unnamed: LED28.2 (DOUT), LED29.4 (DIN)
unnamed: LED29.2 (DOUT), LED30.4 (DIN)
unnamed: LED30.2 (DOUT), LED31.4 (DIN)
unnamed: LED31.2 (DOUT), LED32.4 (DIN)
unnamed: LED32.2 (DOUT), LED33.4 (DIN)
unnamed: LED33.2 (DOUT), LED34.4 (DIN)
unnamed: LED34.2 (DOUT), LED35.4 (DIN)
unnamed: LED35.2 (DOUT), LED36.4 (DIN)
unnamed: LED36.2 (DOUT), LED37.4 (DIN)
unnamed: LED37.2 (DOUT), LED38.4 (DIN)
unnamed: LED38.2 (DOUT), LED39.4 (DIN)
unnamed: LED39.2 (DOUT), LED40.4 (DIN)
unnamed: LED40.2 (DOUT), LED41.4 (DIN)
unnamed: LED41.2 (DOUT), LED42.4 (DIN)
unnamed: LED42.2 (DOUT), LED43.4 (DIN)
unnamed: LED43.2 (DOUT), LED44.4 (DIN)
unnamed: LED44.2 (DOUT), LED45.4 (DIN)
unnamed: LED45.2 (DOUT), LED46.4 (DIN)
unnamed: LED46.2 (DOUT), LED47.4 (DIN)
unnamed: LED47.2 (DOUT), LED48.4 (DIN)
unnamed: LED48.2 (DOUT), LED49.4 (DIN)
unnamed: LED49.2 (DOUT), LED50.4 (DIN)
unnamed: LED50.2 (DOUT), LED51.4 (DIN)
unnamed: LED51.2 (DOUT), LED52.4 (DIN)
unnamed: LED52.2 (DOUT), LED53.4 (DIN)
unnamed: LED53.2 (DOUT), LED54.4 (DIN)
unnamed: LED54.2 (DOUT), LED55.4 (DIN)
unnamed: LED55.2 (DOUT), LED56.4 (DIN)
unnamed: LED56.2 (DOUT), LED57.4 (DIN)
unnamed: LED57.2 (DOUT), LED58.4 (DIN)
unnamed: LED58.2 (DOUT), LED59.4 (DIN)
unnamed: LED59.2 (DOUT), LED60.4 (DIN)
unnamed: LED60.2 (DOUT), LED61.4 (DIN)
unnamed: LED61.2 (DOUT), LED62.4 (DIN)
unnamed: LED62.2 (DOUT), LED63.4 (DIN)
unnamed: LED63.2 (DOUT), LED64.4 (DIN)
unnamed: LED64.2 (DOUT), LED65.4 (DIN)
unnamed: LED65.2 (DOUT), LED66.4 (DIN)
unnamed: LED66.2 (DOUT), LED67.4 (DIN)
unnamed: LED67.2 (DOUT), LED68.4 (DIN)
unnamed: LED68.2 (DOUT), LED69.4 (DIN)
VDD: LED1.1 (VDD), LED2.1 (VDD), LED3.1 (VDD), LED4.1 (VDD), LED5.1 (VDD), LED6.1 (VDD), LED7.1 (VDD), LED8.1 (VDD), LED9.1 (VDD), LED10.1 (VDD), LED11.1 (VDD), LED12.1 (VDD), LED13.1 (VDD), LED14.1 (VDD), LED15.1 (VDD), LED16.1 (VDD), LED17.1 (VDD), LED18.1 (VDD), LED19.1 (VDD), LED20.1 (VDD), LED21.1 (VDD), LED22.1 (VDD), LED23.1 (VDD), LED24.1 (VDD), LED25.1 (VDD), LED26.1 (VDD), LED27.1 (VDD), LED28.1 (VDD), LED29.1 (VDD), LED30.1 (VDD), LED31.1 (VDD), LED32.1 (VDD), LED33.1 (VDD), LED34.1 (VDD), LED35.1 (VDD), LED36.1 (VDD), LED37.1 (VDD), LED38.1 (VDD), LED39.1 (VDD), LED40.1 (VDD), LED41.1 (VDD), LED42.1 (VDD), LED43.1 (VDD), LED44.1 (VDD), LED45.1 (VDD), LED46.1 (VDD), LED47.1 (VDD), LED48.1 (VDD), LED49.1 (VDD), LED50.1 (VDD), LED51.1 (VDD), LED52.1 (VDD), LED53.1 (VDD), LED54.1 (VDD), LED55.1 (VDD), LED56.1 (VDD), LED57.1 (VDD), LED58.1 (VDD), LED59.1 (VDD), LED60.1 (VDD), LED61.1 (VDD), LED62.1 (VDD), LED63.1 (VDD), LED64.1 (VDD), LED65.1 (VDD), LED66.1 (VDD), LED67.1 (VDD), LED68.1 (VDD), LED69.1 (VDD), U1.38 (VBUS)
VSS: LED1.3 (VSS), LED2.3 (VSS), LED3.3 (VSS), LED4.3 (VSS), LED5.3 (VSS), LED6.3 (VSS), LED7.3 (VSS), LED8.3 (VSS), LED9.3 (VSS), LED10.3 (VSS), LED11.3 (VSS), LED12.3 (VSS), LED13.3 (VSS), LED14.3 (VSS), LED15.3 (VSS), LED16.3 (VSS), LED17.3 (VSS), LED18.3 (VSS), LED19.3 (VSS), LED20.3 (VSS), LED21.3 (VSS), LED22.3 (VSS), LED23.3 (VSS), LED24.3 (VSS), LED25.3 (VSS), LED26.3 (VSS), LED27.3 (VSS), LED28.3 (VSS), LED29.3 (VSS), LED30.3 (VSS), LED31.3 (VSS), LED32.3 (VSS), LED33.3 (VSS), LED34.3 (VSS), LED35.3 (VSS), LED36.3 (VSS), LED37.3 (VSS), LED38.3 (VSS), LED39.3 (VSS), LED40.3 (VSS), LED41.3 (VSS), LED42.3 (VSS), LED43.3 (VSS), LED44.3 (VSS), LED45.3 (VSS), LED46.3 (VSS), LED47.3 (VSS), LED48.3 (VSS), LED49.3 (VSS), LED50.3 (VSS), LED51.3 (VSS), LED52.3 (VSS), LED53.3 (VSS), LED54.3 (VSS), LED55.3 (VSS), LED56.3 (VSS), LED57.3 (VSS), LED58.3 (VSS), LED59.3 (VSS), LED60.3 (VSS), LED61.3 (VSS), LED62.3 (VSS), LED63.3 (VSS), LED64.3 (VSS), LED65.3 (VSS), LED66.3 (VSS), LED67.3 (VSS), LED68.3 (VSS), LED69.3 (VSS), U1.15 (GND)
col0: MX1.1, MX16.1, MX31.1, MX45.1, MX60.1, U1.7 (PA0)
col1: MX2.1, MX17.1, MX32.1, MX46.1, MX61.1, U1.8 (PA1)
col2: MX3.1, MX18.1, MX33.1, MX47.1, MX62.1, U1.9 (PA2)
col3: MX4.1, MX19.1, MX34.1, MX48.1, U1.10 (PA3)
col4: MX5.1, MX20.1, MX35.1, MX49.1, U1.11 (PA4)
col5: MX6.1, MX21.1, MX36.1, MX50.1, U1.12 (PA5)
col6: MX7.1, MX22.1, MX37.1, MX51.1, MX63.1, U1.13 (PA6)
col7: MX8.1, MX23.1, MX38.1, MX52.1, U1.14 (PA7)
col8: MX9.1, MX24.1, MX39.1, MX53.1, U1.16 (PD6)
col9: MX10.1, MX25.1, MX40.1, MX54.1, MX64.1, U1.17 (PD7)
col10: MX11.1, MX26.1, MX41.1, MX55.1, MX65.1, U1.21 (PF0)
col11: MX12.1, MX27.1, MX42.1, MX56.1, MX66.1, U1.20 (PF1)
col12: MX13.1, MX28.1, MX43.1, MX57.1, MX67.1, U1.22 (PF3)
col13: MX14.1, MX29.1, MX58.1, MX68.1, U1.31 (PF5)
col14: MX15.1, MX30.1, MX44.1, MX59.1, MX69.1, U1.32 (PF4)
row0: D1.1 (K), D2.1 (K), D3.1 (K), D4.1 (K), D5.1 (K), D6.1 (K), D7.1 (K), D8.1 (K), D9.1 (K), D10.1 (K), D11.1 (K), D12.1 (K), D13.1 (K), D14.1 (K), D15.1 (K), U1.30 (PD0)
row1: D16.1 (K), D17.1 (K), D18.1 (K), D19.1 (K), D20.1 (K), D21.1 (K), D22.1 (K), D23.1 (K), D24.1 (K), D25.1 (K), D26.1 (K), D27.1 (K), D28.1 (K), D29.1 (K), D30.1 (K), U1.29 (PD1)
row2: D31.1 (K), D32.1 (K), D33.1 (K), D34.1 (K), D35.1 (K), D36.1 (K), D37.1 (K), D38.1 (K), D39.1 (K), D40.1 (K), D41.1 (K), D42.1 (K), D43.1 (K), D44.1 (K), U1.28 (PD2)
row3: D45.1 (K), D46.1 (K), D47.1 (K), D48.1 (K), D49.1 (K), D50.1 (K), D51.1 (K), D52.1 (K), D53.1 (K), D54.1 (K), D55.1 (K), D56.1 (K), D57.1 (K), D58.1 (K), D59.1 (K), U1.27 (PD3)
row4: D60.1 (K), D61.1 (K), D62.1 (K), D63.1 (K), D64.1 (K), D65.1 (K), D66.1 (K), D67.1 (K), D68.1 (K), D69.1 (K), U1.25 (PD5)

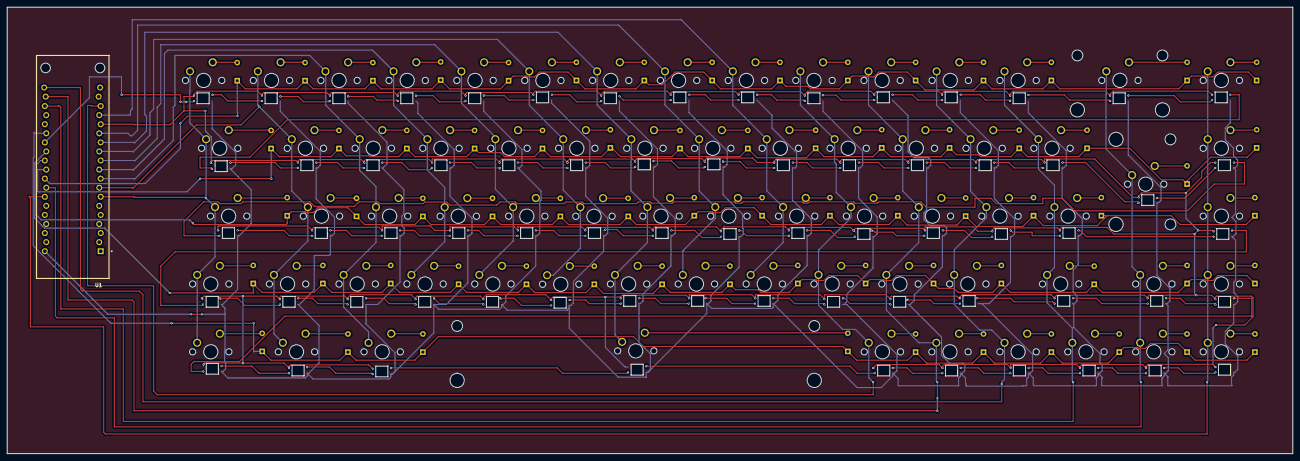
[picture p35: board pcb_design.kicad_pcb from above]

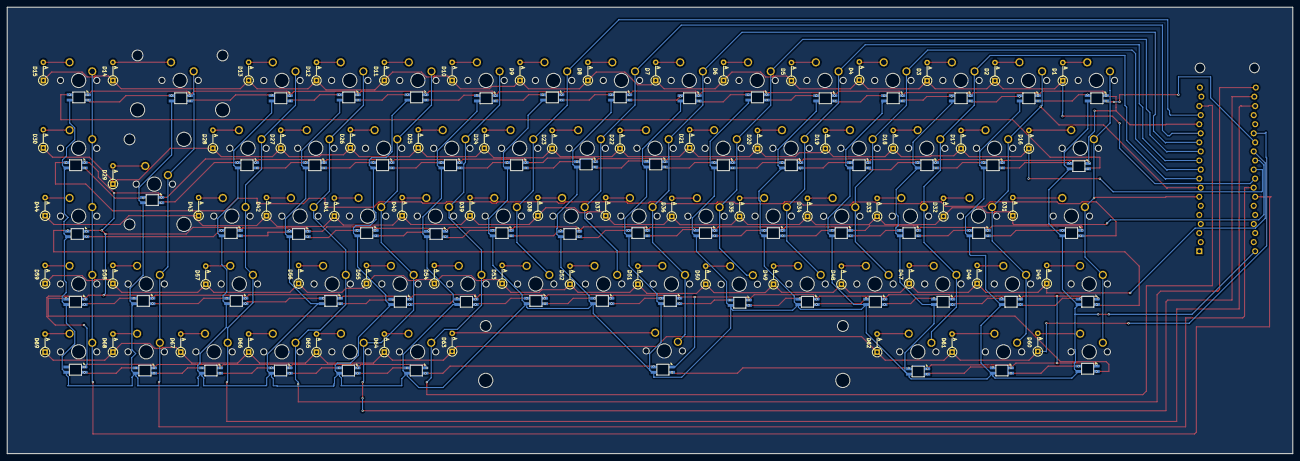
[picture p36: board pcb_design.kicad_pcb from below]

Board: 2 copper layers, 360.0 x 125.0 mm, 211 parts (138 on the bottom side), 160 nets.

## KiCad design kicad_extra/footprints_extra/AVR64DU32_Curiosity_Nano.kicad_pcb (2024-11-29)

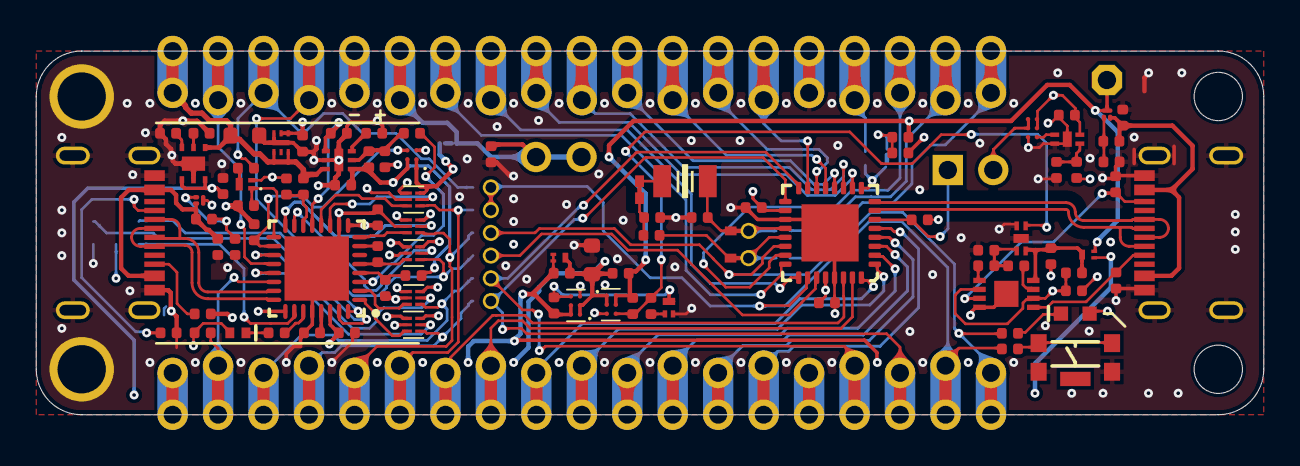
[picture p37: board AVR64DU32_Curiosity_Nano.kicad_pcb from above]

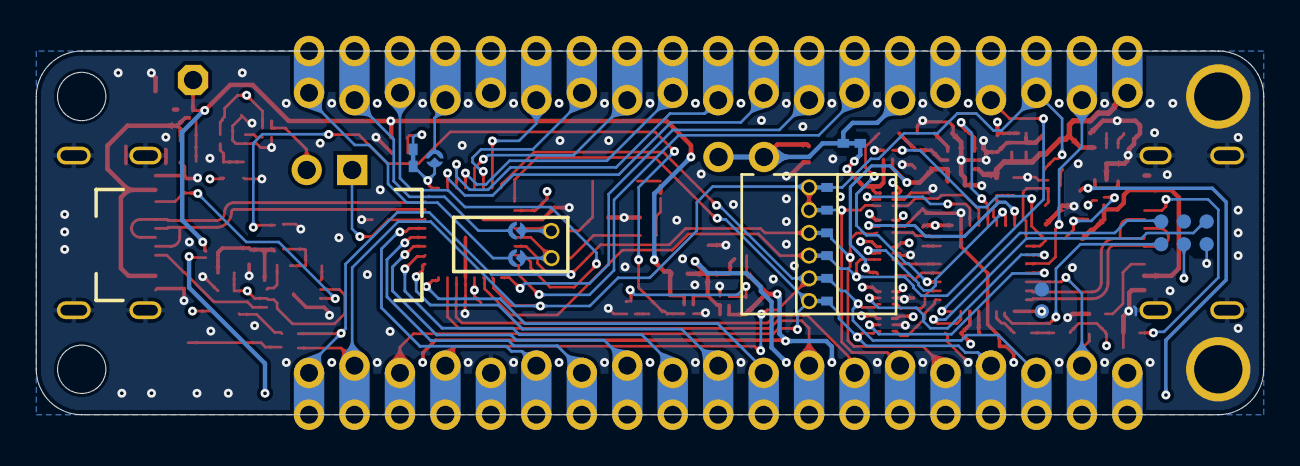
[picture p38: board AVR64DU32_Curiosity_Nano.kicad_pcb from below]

Board: 4 copper layers, 68.6 x 20.3 mm, 114 parts (17 on the bottom side), 106 nets.

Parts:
C100, C101, C102, C103, C104, C105, C106, C107, C200, C201, C202, C203, C204, C206, C207, C208, C209, C301, C303: CAP_C_0402
C205, C300: CAP_C_0603
D100: LED_0603_Yellow
D200: LED_0402_GREEN
D300, D301: X3-DSN1006-3
J100: CON_EDGE_CNANO-38
J101, J102, J103, J104, J105, J106, J109, J110: CON_JMPR_0402_PCB_TRACE_LINK_0.9mm_PAD_0.6mm_PTH
J107, J108, J113: CON_JMPR_1mmX1mm_ROUND_SOLDER-STRAP
J111, J116, J200: CON_JMPR_0402_PCB_TRACE_LINK
J112, J203: CON_USB2.0-C_RCPT_SMD_RA_KLS_KLS1-5409
J114: HDR_M_2.54_1x2_U_TH-PIP_V_WCON_1125-1102S0S113R1
J115: HDR_M_2.54_1x1
J201: CON_JMPR_2.54_1x2_TH_PCB_TRACE_LINK
J202: TESTPOINT_ARRAY_2x3_1.27mm_pitch_SMD
JP100: Jumper_Mechanical
LABEL1: 08-10015
Q100, Q201: LGA-3_GSD_0.7x0.6_CSD25501F3
Q200, Q300: X1-DFN1006-3
R100, R101, R102, R103, R104, R105, R106, R107, R108, R109, R110, R200, R201, R202, R203, R204, R205, R206, R207, R208, R209, R210, R211, R212, R213, R214, R215, R216, R217, R218, R300, R301, R302, R303, R304, R305, R306, R307, R308: RES_C_0402
SW100: SW_TACT_SMD_KLS_L-KLS7-TS0304A-2-300-T
TP200, TP201: TP_3.6X2.7
TP202, TP203: CON_TP_0.8dia_SMD_with_Test_Jig_Layer
U100: VQFN-32_5X5_EP3.2X3.2
U101: WLCSP-6_L1W1.5H0.5
U102, U303: TDFN-4_1.6x1.2
U200: MLF-6 1.6X1.6mm
U201, U300, U301: MIC94163_1.5MM_1MM
U202: VDFN-6_2x2_EP0.8X1.40
U203: DFN-6_1.2x1.2
U204, U205, U207, U208, U209: X2-DFN1010-6
U206: QFN-32_5X5_EP3.6x3.6_L
U302: TDFN-8_2X3_EP1.46X1.36
Y100: CRYSTAL_VMK3_L3.2W1.5H0.9

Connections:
BOOT: TP202.1, U206.25
CDC_RX: J100.3, J101.1, U208.4
CDC_RX_CTRL: U206.19, U208.5
CDC_TX: J100.4, J103.1, U209.4
CDC_TX_CTRL: U206.21, U209.5
DAC: R208.2, U206.3
DBG0: J100.35, J104.1, U207.4
DBG0_CTRL: U206.15, U207.5
DBG1: J100.5, J105.1, U205.4
DBG1_CTRL: U205.5, U206.16
DBG2: J100.6, J106.1, U204.4
DBG2_CTRL: U204.5, U206.11
DBG2_GPIO: U204.3, U206.12
DBG3: J100.36, J102.1, R209.2
DBG3_CTRL: Q200.1, R210.1, U206.17
GND: C100.2, C101.2, C103.1, C104.1, C105.2, C106.1, C107.2, C200.1, C201.2, C202.1, C203.1, C204.1, C205.1, C206.1, C207.2, C209.1, C300.1, C301.1, C303.1, J100.15, J100.24, J100.34, J112.1, J112.2, J112.3, J112.4, J112.A1/B12, J112.B1/A12, J202.2, J203.1, J203.2, J203.3, J203.4, J203.A1/B12, J203.B1/A12, Q200.2, Q300.2, R100.1, R101.2, R102.2, R105.2, R107.1, R109.1, R203.2, R204.2, R205.1, R206.1, R207.1, R210.2, R211.2, R213.2, R214.2, R216.2, R217.2, R306.1, SW100.1, SW100.2, TP200.1, TP201.1, TP203.1, U100.19, U100.29, U100.33, U101.C1, U102.2, U102.5, U200.2, U200.7, U201.C1, U202.5, U202.7, U203.3, U203.7, U204.2, U205.2, U206.10, U206.28, U206.33, U207.2, U208.2, U209.2, U300.C1, U301.C1, U302.4, U302.9, U303.2, U303.5
ID_SYS: J100.2, R218.1, U206.22
MUX_CONTROL: R302.2, R307.1, U300.C2, U303.1
NetC102_1: C102.1, Q100.1, R101.1
NetC104_2: C104.2, J109.1, Y100.1
NetC105_1: C105.1, J111.1, R110.1
NetC201_1: C201.1, U200.6
NetC206_2: C206.2, U202.2
NetC208_1: C208.1, Q201.1, R214.1
NetD100_2: D100.2, R104.2
NetD200_2: D200.2, R215.1
NetJ110_1: J110.1, R110.2
NetJ111_2: J111.2, Y100.2
NetJ114_2: J114.2, U101.A1, U101.B1
NetJ116_1: J116.1, R108.1, R109.2
NetJ203_A5: J203.A5, R217.1
NetJ203_B5: J203.B5, R216.1
NetQ200_3: Q200.3, R209.1
NetQ300_1: Q300.1, R307.2
NetQ300_3: Q300.3, R303.1, U301.C2
NetR103_2: R103.2, SW100.3, SW100.4
NetR106_1: R106.1, R107.2, U102.3
NetR211_1: R211.1, U202.3
NetR305_2: R305.2, U302.1
NetR308_1: R308.1, U302.7
NetU101_C2: U101.C2, U102.1
PA0_USART0_TX: J100.7, U100.30
PA1_USART0_RX: J100.8, U100.31
PA2_I2C0_SDA: J100.9, U100.32
PA3_I2C0_SCL: J100.10, U100.1
PA4_SPI0_MOSI: J100.11, U100.2
PA5_SPI0_MISO: J100.12, U100.3
PA6_SPI0_SCK: J100.13, U100.4
PA7_SPI0_SS: J100.14, U100.5
PC3: J100.23, J113.2
PC3_VBUS_TARGET_DETECT: J113.1, J116.2, U100.9
PD0_AIN0: J100.30, U100.10
PD1_AIN1: J100.29, U100.11
PD2_AIN2: J100.28, U100.12
PD3_AIN3: J100.27, U100.13
PD4_AIN4: J100.26, U100.14
PD5_AIN5: J100.25, U100.15
PD6_USART1_TX: J100.16, J101.2, U100.16
PD7_USART1_RX: J100.17, J103.2, U100.17
PF0: J100.21, J107.2
PF0_XTAL32K1: J107.1, J109.2, U100.20
PF1: J100.20, J108.2
PF1_XTAL32K2: J108.1, J110.2, U100.21
PF2_LED0_DBG1: J100.19, J105.2, R104.1, U100.22
PF3: J100.22, U100.23
PF4_AIN20: J100.32, U100.24
PF5_AIN21: J100.31, U100.25
PF6_SW0_DBG2: J100.18, J102.2, J106.2, R103.1, U100.26
PF7_UPDI: J104.2, U100.27
REG_ADJUST: R201.2, R206.2, R208.1, U200.5
REG_ENABLE: R204.1, U200.1, U206.13
S0_0_RX: R212.1, U206.5, U207.3
S0_2_TX: R212.2, U206.7
S0_3_CLK: U205.3, U206.8
S1_0_TX: U206.1, U209.3
S1_1_RX: U206.2, U208.3
STATUS_LED: R215.2, U206.27
SWCLK: J202.1, U206.31
SWDIO: J202.5, U206.32
TARGET_CC1: J112.A5, R105.1, U302.5
TARGET_CC2: J112.B5, R102.1, U302.3
USBD_N: J203.A7, J203.B7, U206.23
USBD_P: J203.A6, J203.B6, U206.24
USBT_N: J112.A7, J112.B7, U100.7
USBT_P: J112.A6, J112.B6, U100.8
VBUS_ADC: R200.2, R205.2, U206.14
VBUS_DEBUG: C208.2, J203.A4/B9, J203.B4/A9, Q201.2, R213.1
VBUS_DEBUG_DELAYED: D300.2, D300.3, D301.2, Q201.3, R301.1, R303.2, U301.A2, U301.B2
VBUS_MUX_OUT: C204.2, C300.2, D300.1, R300.1, R301.2, U202.4, U202.6, U300.A1, U300.B1, U301.A1, U301.B1
VBUS_MUX_VCC: C301.2, D301.1, R304.2, U302.8, U303.4
VBUS_TARGET: C102.2, J112.A4/B9, J112.B4/A9, Q100.2, R100.2
VBUS_TARGET_DELAYED: D301.3, J115.1, Q100.3, R108.2, R300.2, R302.1, U300.A2, U300.B2
VBUS_TARGET_EN: C303.2, R305.1, R308.2, U303.3
VCC_EDGE: C103.2, J100.33, J200.2, J201.1
VCC_LEVEL: J200.1, U201.A1, U201.B1, U204.6, U205.6, U207.6, U208.6, U209.6
VCC_MCU_CORE: C209.2, U206.29
VCC_P3V3: C107.1, C202.2, C203.2, C207.1, D200.1, J202.4, R218.2, U101.A2, U101.B2, U102.4, U203.1, U203.2, U204.1, U205.1, U206.9, U206.30, U207.1, U208.1, U209.1
VCC_REGULATOR: C200.2, R201.1, R202.2, U200.4, U201.A2, U201.B2
VCC_TARGET: C100.1, C101.1, D100.1, J201.2, R106.2, U100.18, U100.28
VCC_VBUS: C205.2, J100.38, R200.1, U200.3, U202.1, U203.4, U203.6
VREF_P0V320: R304.1, R306.2, U302.2, U302.6
VTG_ADC: R202.1, R207.2, U206.4
VTG_EN: R203.1, U201.C2, U206.18
VUSB_TARGET: C106.2, J114.1, U100.6
~SRST: J202.6, U206.26
~VOFF: J100.37, U206.20

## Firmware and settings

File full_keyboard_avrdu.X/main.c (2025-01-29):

 /*
 * MAIN Generated Driver File
 * 
 * @file main.c
 * 
 * @defgroup main MAIN
 * 
 * @brief This is the generated driver implementation file for the MAIN driver.
 *
 * @version MAIN Driver Version 1.0.2
 *
 * @version Package Version: 3.1.2
*/

/*
© [2025] Microchip Technology Inc. and its subsidiaries.

    Subject to your compliance with these terms, you may use Microchip 
    software and any derivatives exclusively with Microchip products. 
    You are responsible for complying with 3rd party license terms  
    applicable to your use of 3rd party software (including open source  
    software) that may accompany Microchip software. SOFTWARE IS ?AS IS.? 
    NO WARRANTIES, WHETHER EXPRESS, IMPLIED OR STATUTORY, APPLY TO THIS 
    SOFTWARE, INCLUDING ANY IMPLIED WARRANTIES OF NON-INFRINGEMENT,  
    MERCHANTABILITY, OR FITNESS FOR A PARTICULAR PURPOSE. IN NO EVENT 
    WILL MICROCHIP BE LIABLE FOR ANY INDIRECT, SPECIAL, PUNITIVE, 
    INCIDENTAL OR CONSEQUENTIAL LOSS, DAMAGE, COST OR EXPENSE OF ANY 
    KIND WHATSOEVER RELATED TO THE SOFTWARE, HOWEVER CAUSED, EVEN IF 
    MICROCHIP HAS BEEN ADVISED OF THE POSSIBILITY OR THE DAMAGES ARE 
    FORESEEABLE. TO THE FULLEST EXTENT ALLOWED BY LAW, MICROCHIP?S 
    TOTAL LIABILITY ON ALL CLAIMS RELATED TO THE SOFTWARE WILL NOT 
    EXCEED AMOUNT OF FEES, IF ANY, YOU PAID DIRECTLY TO MICROCHIP FOR 
    THIS SOFTWARE.
*/
// Generated files
#include "mcc_generated_files/system/system.h"
#include "mcc_generated_files/system/pins.h"

// Custom files
#include "usb.h"
#include "hardware.h"
#include "keyboard.h"

#define NUM_COLUMNS 15
#define NUM_ROWS 5

// Flags to keep track of all key states
volatile bool buttonChangeFlag[NUM_ROWS][NUM_COLUMNS] = {false};
volatile bool buttonPressed[NUM_ROWS][NUM_COLUMNS] = {false};
volatile uint8_t activeRow = 0;

// Flags to keep track of key changes
volatile bool keyChanges = false;
volatile bool keyDown = true;
volatile uint8_t keyboardIndex = -1;
volatile bool layer2Active = false;

// Check columns for key presses, called every 1 ms
void IterateColumns(void);

// Handles keypresses
void KeyPressHandler(uint8_t currentRow);
void KeyUpEvent(void);
void KeyDownEvent(void);
void DetectKeyChanges(uint8_t currentRow);
       
int main(void)
{
    USBDevice_StartOfFrameCallbackRegister(IterateColumns); // Called every 1 ms
    SYSTEM_Initialize();
    RTC_SetPITIsrCallback(CheckUSBConnection);

    while(1)
    {
        HandleUSBConnection();
         
        // Handle key presses in the activeRow
        KeyPressHandler(activeRow);
    }    
}

void KeyPressHandler(uint8_t currentRow) // Handles key presses
{
    DetectKeyChanges(currentRow);
    
    if (keyChanges)
    {
        // Checks if we need the key press down event
        if (keyDown)
        {
            KeyDownEvent();
        }
         // Key press up event
        else
        {
            KeyUpEvent();
        }
    }
}

void KeyUpEvent(void)
{

    if (SUCCESS == status)
    {
        if(layer2Active && IsCustomIndex(keyboardIndex))
        {
            status = USB_HIDKeyPressUp(layer2[keyboardIndex]);
            USB_HIDKeyModifierDown(ALTGR);
        }else
        {
            if(IsModifierIndex(keyboardIndex))
            {
                status = USB_HIDKeyModifierUp(keyboard[keyboardIndex]);
                if(keyboardIndex == ALTGR_INDEX)
                {
                    layer2Active = false;
                }
            }
            else
            {
              // Sends the key press up event
               status = USB_HIDKeyPressUp(keyboard[keyboardIndex]);
            }
        }
    }
}

void KeyDownEvent(void)
{
    if (SUCCESS == status)
    {
        if (IsModifierIndex(keyboardIndex))
        {
            status = USB_HIDKeyModifierDown(keyboard[keyboardIndex]);
            if(keyboardIndex == ALTGR_INDEX)
            {
                layer2Active = true;
            }
        }
        else
        {
          // Sends the key press down event
            if(layer2Active && IsCustomIndex(keyboardIndex))
            {
                status = USB_HIDKeyModifierUp(ALTGR);   // release altgr
                status = USB_HIDKeyPressDown(layer2[keyboardIndex]);
            }
            else
            {
                status = USB_HIDKeyPressDown(keyboard[keyboardIndex]);
            }
        }
    }
}

void DetectKeyChanges(uint8_t currentRow){
    
    // Detect button change
    for (uint8_t currentColumn = 0; currentColumn < NUM_COLUMNS; currentColumn++) 
    {
        if(buttonChangeFlag[currentRow][currentColumn])
        {
            if (buttonPressed[currentRow][currentColumn])
            {
                keyDown = true;
            }else
            {
                keyDown = false;
            }
            keyboardIndex = currentColumn + currentRow*NUM_COLUMNS;
            keyChanges = true;
            buttonChangeFlag[currentRow][currentColumn] = false;
            break;
        }
        keyChanges = false;
    }
}

void IterateColumns(void) // called every 1 ms
{  
    // Iterate columns
    for (int col=0; col < NUM_COLUMNS; col++){
        // Check key down event
        if (ColumnIsActive(col)){
                if (buttonPressed[activeRow][col] == false)
                {
                    buttonPressed[activeRow][col] = true;
                    buttonChangeFlag[activeRow][col] = true;
                }
        }
        // Check key up event
        else if (buttonPressed[activeRow][col] == true)
        {
            buttonPressed[activeRow][col] = false;
            buttonChangeFlag[activeRow][col] = true;
        }
    }
    
    // Go to the next row
    TurnRowOff(activeRow);
    activeRow = (activeRow+1)%NUM_ROWS; 
    TurnRowOn(activeRow);
 
    return;
}

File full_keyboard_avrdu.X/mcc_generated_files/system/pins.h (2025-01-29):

/**
 * Generated Pins header File
 * 
 * @file pins.h
 * 
 * @defgroup  pinsdriver Pins Driver
 * 
 * @brief This is generated driver header for pins. 
 *        This header file provides APIs for all pins selected in the GUI.
 *
 * @version Driver Version  1.1.0
*/

/*
© [2025] Microchip Technology Inc. and its subsidiaries.

    Subject to your compliance with these terms, you may use Microchip 
    software and any derivatives exclusively with Microchip products. 
    You are responsible for complying with 3rd party license terms  
    applicable to your use of 3rd party software (including open source  
    software) that may accompany Microchip software. SOFTWARE IS ?AS IS.? 
    NO WARRANTIES, WHETHER EXPRESS, IMPLIED OR STATUTORY, APPLY TO THIS 
    SOFTWARE, INCLUDING ANY IMPLIED WARRANTIES OF NON-INFRINGEMENT,  
    MERCHANTABILITY, OR FITNESS FOR A PARTICULAR PURPOSE. IN NO EVENT 
    WILL MICROCHIP BE LIABLE FOR ANY INDIRECT, SPECIAL, PUNITIVE, 
    INCIDENTAL OR CONSEQUENTIAL LOSS, DAMAGE, COST OR EXPENSE OF ANY 
    KIND WHATSOEVER RELATED TO THE SOFTWARE, HOWEVER CAUSED, EVEN IF 
    MICROCHIP HAS BEEN ADVISED OF THE POSSIBILITY OR THE DAMAGES ARE 
    FORESEEABLE. TO THE FULLEST EXTENT ALLOWED BY LAW, MICROCHIP?S 
    TOTAL LIABILITY ON ALL CLAIMS RELATED TO THE SOFTWARE WILL NOT 
    EXCEED AMOUNT OF FEES, IF ANY, YOU PAID DIRECTLY TO MICROCHIP FOR 
    THIS SOFTWARE.
*/

#ifndef PINS_H_INCLUDED
#define PINS_H_INCLUDED

#include <avr/io.h>
#include "./port.h"

//get/set VBUS aliases
#define VBUS_SetHigh() do { PORTC_OUTSET = 0x8; } while(0)
#define VBUS_SetLow() do { PORTC_OUTCLR = 0x8; } while(0)
#define VBUS_Toggle() do { PORTC_OUTTGL = 0x8; } while(0)
#define VBUS_GetValue() (VPORTC.IN & (0x1 << 3))
#define VBUS_SetDigitalInput() do { PORTC_DIRCLR = 0x8; } while(0)
#define VBUS_SetDigitalOutput() do { PORTC_DIRSET = 0x8; } while(0)
#define VBUS_SetPullUp() do { PORTC_PIN3CTRL  |= PORT_PULLUPEN_bm; } while(0)
#define VBUS_ResetPullUp() do { PORTC_PIN3CTRL  &= ~PORT_PULLUPEN_bm; } while(0)
#define VBUS_SetInverted() do { PORTC_PIN3CTRL  |= PORT_INVEN_bm; } while(0)
#define VBUS_ResetInverted() do { PORTC_PIN3CTRL  &= ~PORT_INVEN_bm; } while(0)
#define VBUS_DisableInterruptOnChange() do { PORTC.PIN3CTRL = (PORTC.PIN3CTRL & ~PORT_ISC_gm) | 0x0 ; } while(0)
#define VBUS_EnableInterruptForBothEdges() do { PORTC.PIN3CTRL = (PORTC.PIN3CTRL & ~PORT_ISC_gm) | 0x1 ; } while(0)
#define VBUS_EnableInterruptForRisingEdge() do { PORTC.PIN3CTRL = (PORTC.PIN3CTRL & ~PORT_ISC_gm) | 0x2 ; } while(0)
#define VBUS_EnableInterruptForFallingEdge() do { PORTC.PIN3CTRL = (PORTC.PIN3CTRL & ~PORT_ISC_gm) | 0x3 ; } while(0)
#define VBUS_DisableDigitalInputBuffer() do { PORTC.PIN3CTRL = (PORTC.PIN3CTRL & ~PORT_ISC_gm) | 0x4 ; } while(0)
#define VBUS_EnableInterruptForLowLevelSensing() do { PORTC.PIN3CTRL = (PORTC.PIN3CTRL & ~PORT_ISC_gm) | 0x5 ; } while(0)
#define PC3_SetInterruptHandler VBUS_SetInterruptHandler

//get/set COL0 aliases
#define COL0_SetHigh() do { PORTA_OUTSET = 0x1; } while(0)
#define COL0_SetLow() do { PORTA_OUTCLR = 0x1; } while(0)
#define COL0_Toggle() do { PORTA_OUTTGL = 0x1; } while(0)
#define COL0_GetValue() (VPORTA.IN & (0x1 << 0))
#define COL0_SetDigitalInput() do { PORTA_DIRCLR = 0x1; } while(0)
#define COL0_SetDigitalOutput() do { PORTA_DIRSET = 0x1; } while(0)
#define COL0_SetPullUp() do { PORTA_PIN0CTRL  |= PORT_PULLUPEN_bm; } while(0)
#define COL0_ResetPullUp() do { PORTA_PIN0CTRL  &= ~PORT_PULLUPEN_bm; } while(0)
#define COL0_SetInverted() do { PORTA_PIN0CTRL  |= PORT_INVEN_bm; } while(0)
#define COL0_ResetInverted() do { PORTA_PIN0CTRL  &= ~PORT_INVEN_bm; } while(0)
#define COL0_DisableInterruptOnChange() do { PORTA.PIN0CTRL = (PORTA.PIN0CTRL & ~PORT_ISC_gm) | 0x0 ; } while(0)
#define COL0_EnableInterruptForBothEdges() do { PORTA.PIN0CTRL = (PORTA.PIN0CTRL & ~PORT_ISC_gm) | 0x1 ; } while(0)
#define COL0_EnableInterruptForRisingEdge() do { PORTA.PIN0CTRL = (PORTA.PIN0CTRL & ~PORT_ISC_gm) | 0x2 ; } while(0)
#define COL0_EnableInterruptForFallingEdge() do { PORTA.PIN0CTRL = (PORTA.PIN0CTRL & ~PORT_ISC_gm) | 0x3 ; } while(0)
#define COL0_DisableDigitalInputBuffer() do { PORTA.PIN0CTRL = (PORTA.PIN0CTRL & ~PORT_ISC_gm) | 0x4 ; } while(0)
#define COL0_EnableInterruptForLowLevelSensing() do { PORTA.PIN0CTRL = (PORTA.PIN0CTRL & ~PORT_ISC_gm) | 0x5 ; } while(0)
#define PA0_SetInterruptHandler COL0_SetInterruptHandler

//get/set COL1 aliases
#define COL1_SetHigh() do { PORTA_OUTSET = 0x2; } while(0)
#define COL1_SetLow() do { PORTA_OUTCLR = 0x2; } while(0)
#define COL1_Toggle() do { PORTA_OUTTGL = 0x2; } while(0)
#define COL1_GetValue() (VPORTA.IN & (0x1 << 1))
#define COL1_SetDigitalInput() do { PORTA_DIRCLR = 0x2; } while(0)
#define COL1_SetDigitalOutput() do { PORTA_DIRSET = 0x2; } while(0)
#define COL1_SetPullUp() do { PORTA_PIN1CTRL  |= PORT_PULLUPEN_bm; } while(0)
#define COL1_ResetPullUp() do { PORTA_PIN1CTRL  &= ~PORT_PULLUPEN_bm; } while(0)
#define COL1_SetInverted() do { PORTA_PIN1CTRL  |= PORT_INVEN_bm; } while(0)
#define COL1_ResetInverted() do { PORTA_PIN1CTRL  &= ~PORT_INVEN_bm; } while(0)
#define COL1_DisableInterruptOnChange() do { PORTA.PIN1CTRL = (PORTA.PIN1CTRL & ~PORT_ISC_gm) | 0x0 ; } while(0)
#define COL1_EnableInterruptForBothEdges() do { PORTA.PIN1CTRL = (PORTA.PIN1CTRL & ~PORT_ISC_gm) | 0x1 ; } while(0)
#define COL1_EnableInterruptForRisingEdge() do { PORTA.PIN1CTRL = (PORTA.PIN1CTRL & ~PORT_ISC_gm) | 0x2 ; } while(0)
#define COL1_EnableInterruptForFallingEdge() do { PORTA.PIN1CTRL = (PORTA.PIN1CTRL & ~PORT_ISC_gm) | 0x3 ; } while(0)
#define COL1_DisableDigitalInputBuffer() do { PORTA.PIN1CTRL = (PORTA.PIN1CTRL & ~PORT_ISC_gm) | 0x4 ; } while(0)
#define COL1_EnableInterruptForLowLevelSensing() do { PORTA.PIN1CTRL = (PORTA.PIN1CTRL & ~PORT_ISC_gm) | 0x5 ; } while(0)
#define PA1_SetInterruptHandler COL1_SetInterruptHandler
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

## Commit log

2024-09-09 found leds and diodes
2024-11-11 switched rows and colums, one row working now
2024-11-26 added modifiers, missing alt gr
    [main.c]
2024-11-26 second layer and windows button
2024-11-27 removed cv, added pictures
    [AVR64DU32_Curiosity_Nano.kicad_pcb, MX_SW_RGB.stp, SK6812MINI-E v1.step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]
2024-11-29 added led project
2024-12-01 added pictures, gitignore, readme ish done
    [bom.csv, designators.csv, pcb_design.kicad_pcb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]
2025-01-24 added 3d files for case
2025-01-27 3d stl files
    [keyboard_bottom_left.stl, keyboard_bottom_right.stl, keyboard_support.stl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]
2025-01-28 Main picture update with pink case
2025-01-28 3d case text and images added
2025-01-29 Generic led files
2025-01-29 new vid and pid
2025-01-29 usart0 periphal for leds

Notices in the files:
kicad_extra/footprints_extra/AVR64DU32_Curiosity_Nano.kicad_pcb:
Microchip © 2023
